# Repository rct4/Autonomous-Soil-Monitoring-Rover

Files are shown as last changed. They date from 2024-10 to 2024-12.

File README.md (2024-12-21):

# Autonomous-Soil-Monitoring-Rover

The autonomous soil monitoring rover is a project that aims to assist commercial farmers and personal gardeners by introducing an automated solution to monitoring soil data.

## Software
Motion plan is currently a naive solution, polling each sensor for feedback. A FreeRTOS solution is currently being developed to schedule sensor data collection and motor output.

## PCB
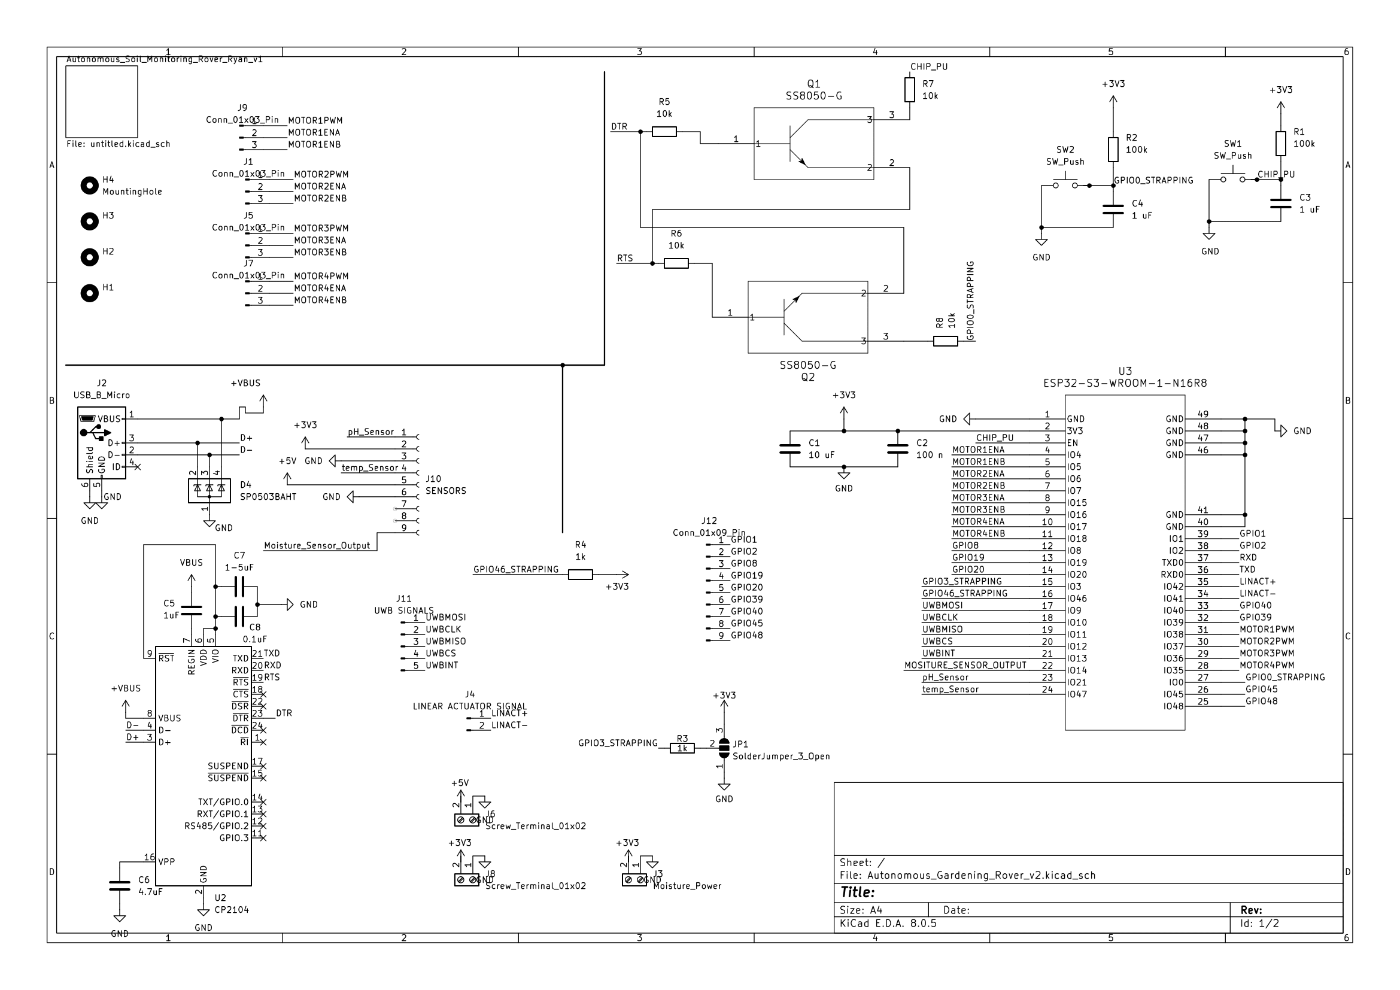
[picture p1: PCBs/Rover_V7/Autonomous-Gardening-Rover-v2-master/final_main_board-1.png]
Rover PCB


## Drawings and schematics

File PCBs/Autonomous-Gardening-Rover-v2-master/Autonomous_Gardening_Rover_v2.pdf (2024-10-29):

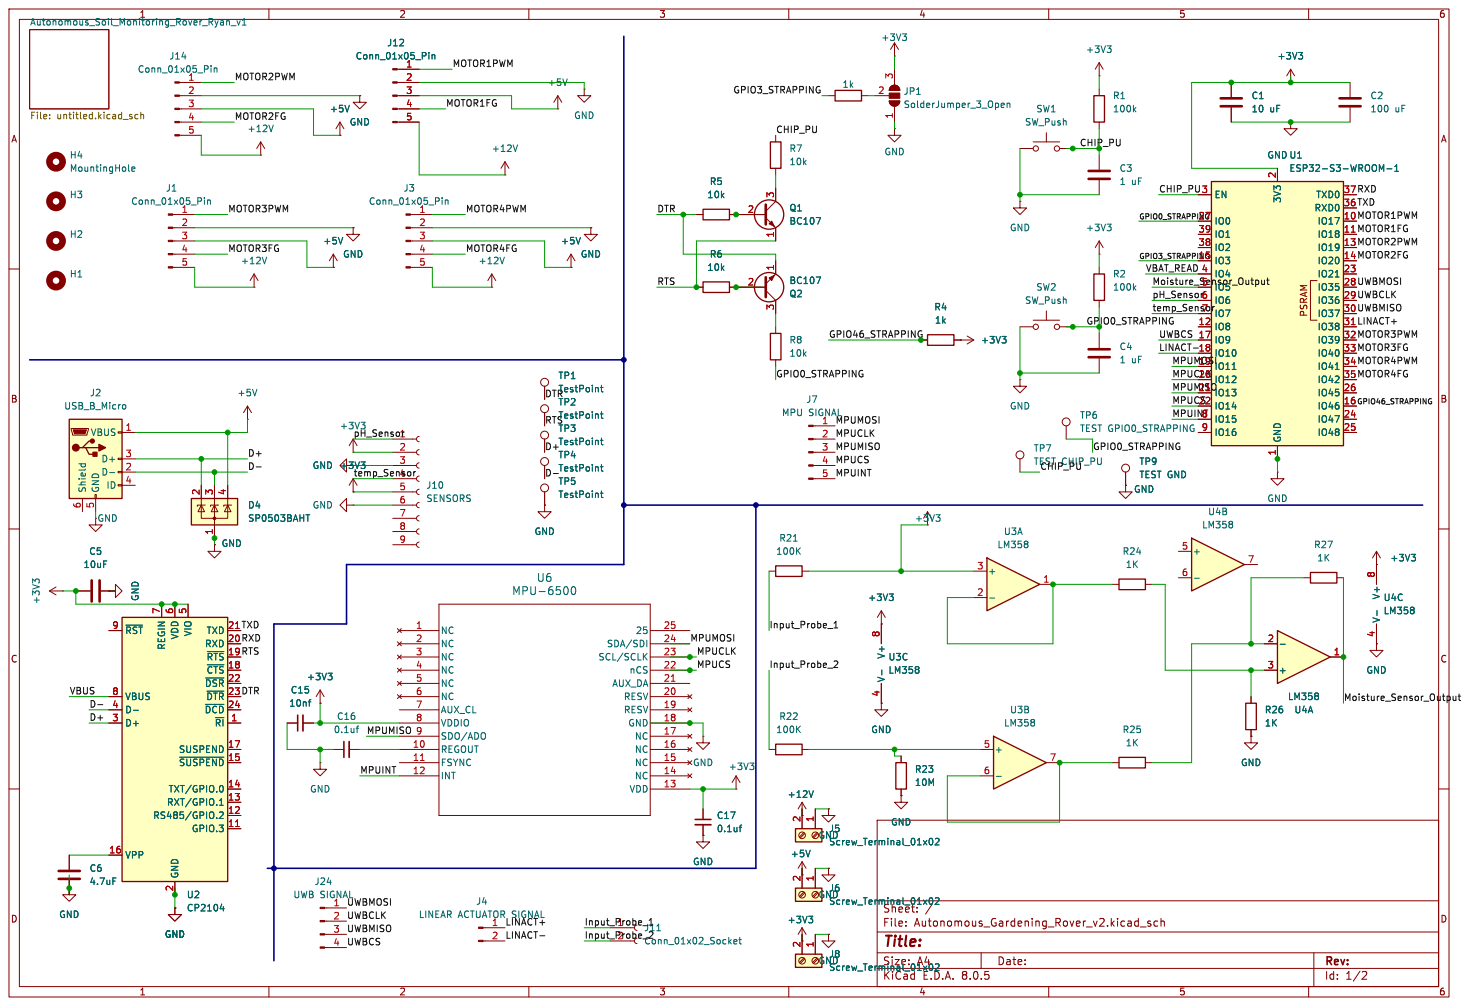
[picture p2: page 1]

LINACT- MPUMOSI MPUCLK MPUMISO MPUINT MPUCS

2 RXD 20 TXD 21 ~{DSR} 22 ~{DTR} 23 ~{DCD} 24 D+ 3 D- 4 VIO

Id: 1/2 Title: File: Autonomous_Gardening_Rover_v2.kicad_sch Sheet: /

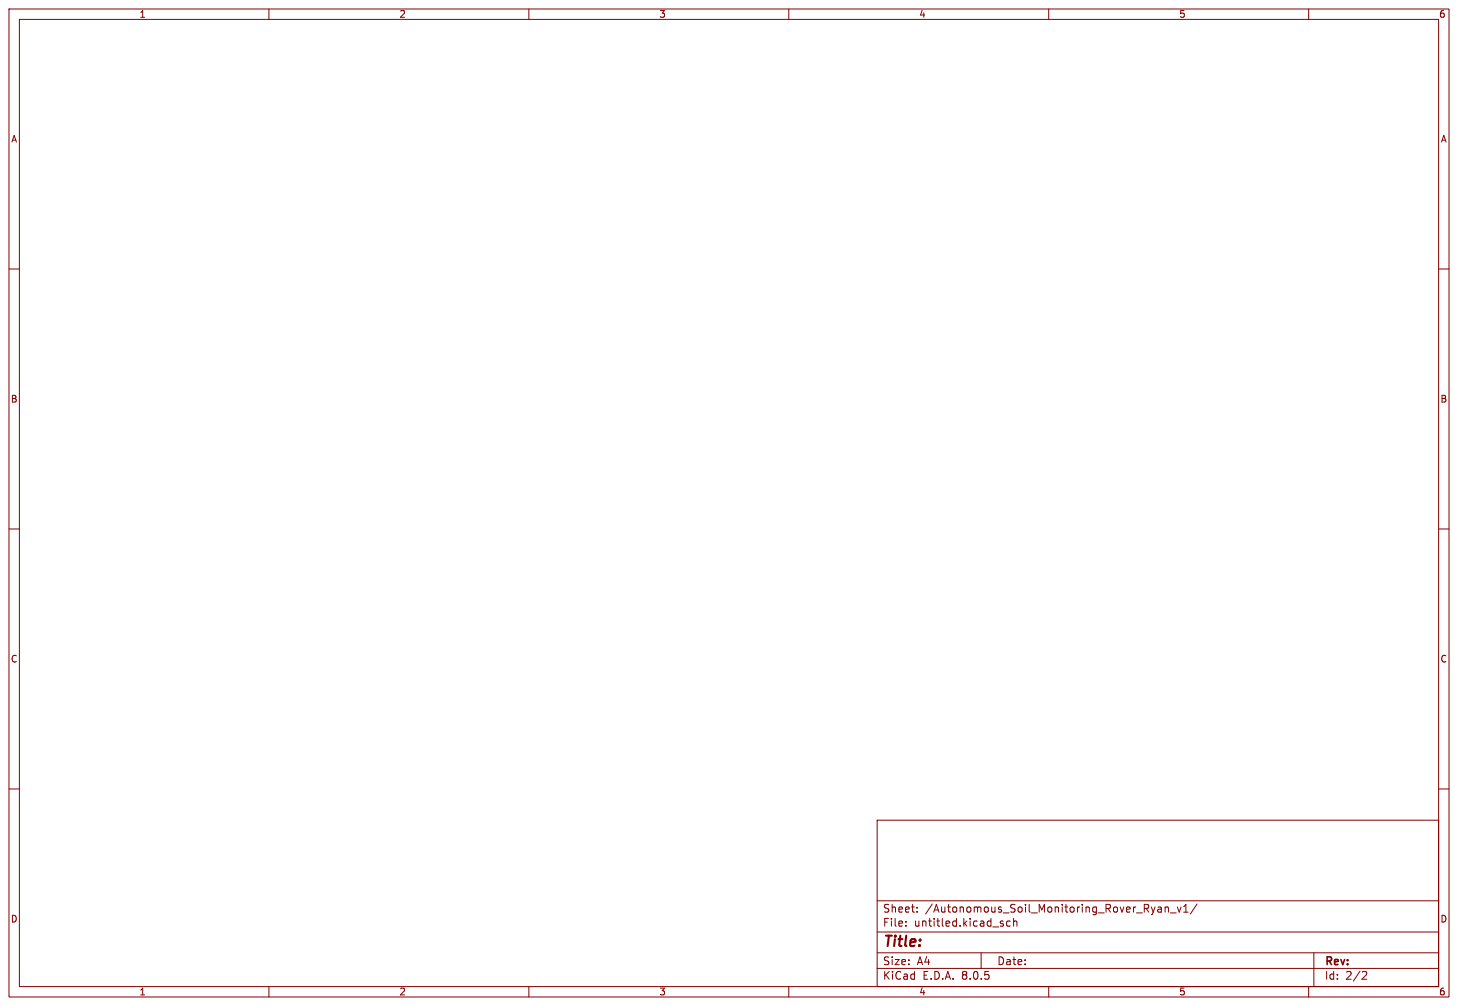
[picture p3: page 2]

Id: 2/2 Title: File: untitled.kicad_sch Sheet: /Autonomous_Soil_Monitoring_Rover_Ryan_v1/

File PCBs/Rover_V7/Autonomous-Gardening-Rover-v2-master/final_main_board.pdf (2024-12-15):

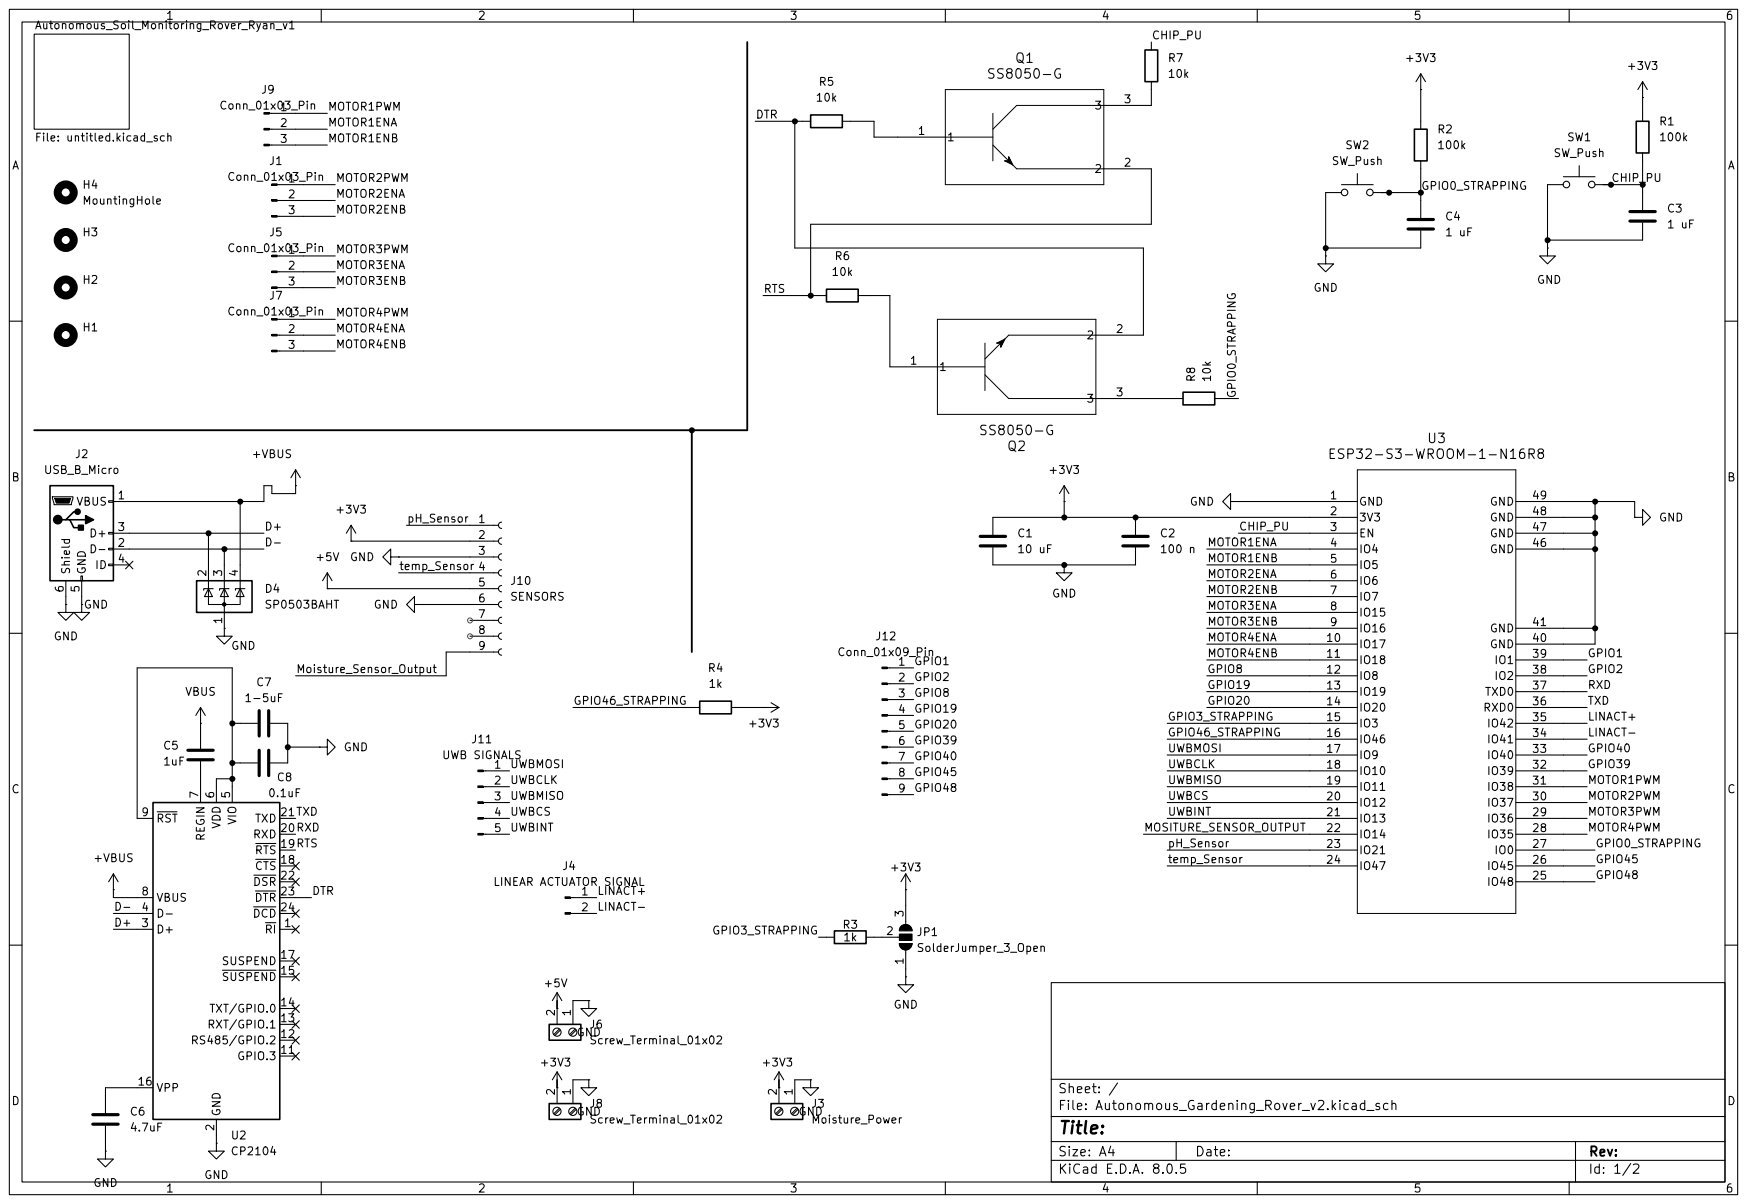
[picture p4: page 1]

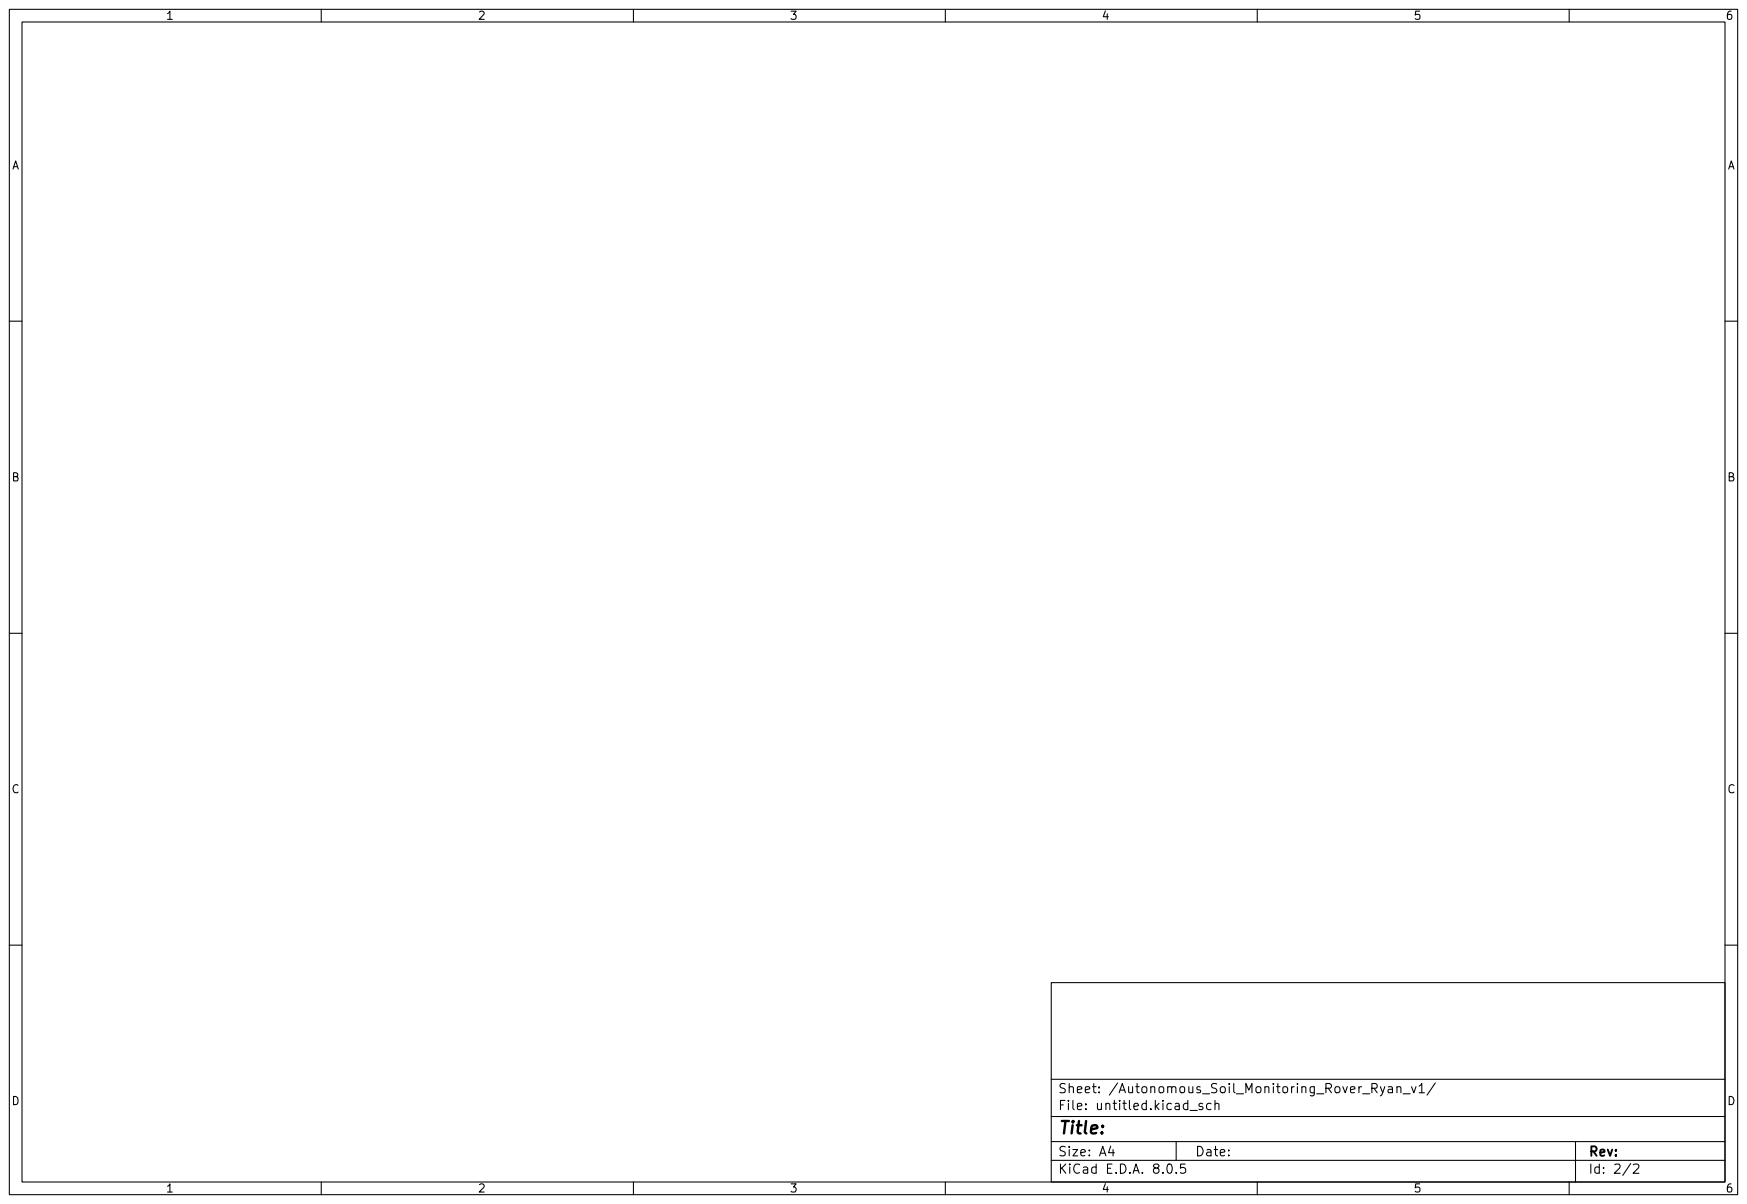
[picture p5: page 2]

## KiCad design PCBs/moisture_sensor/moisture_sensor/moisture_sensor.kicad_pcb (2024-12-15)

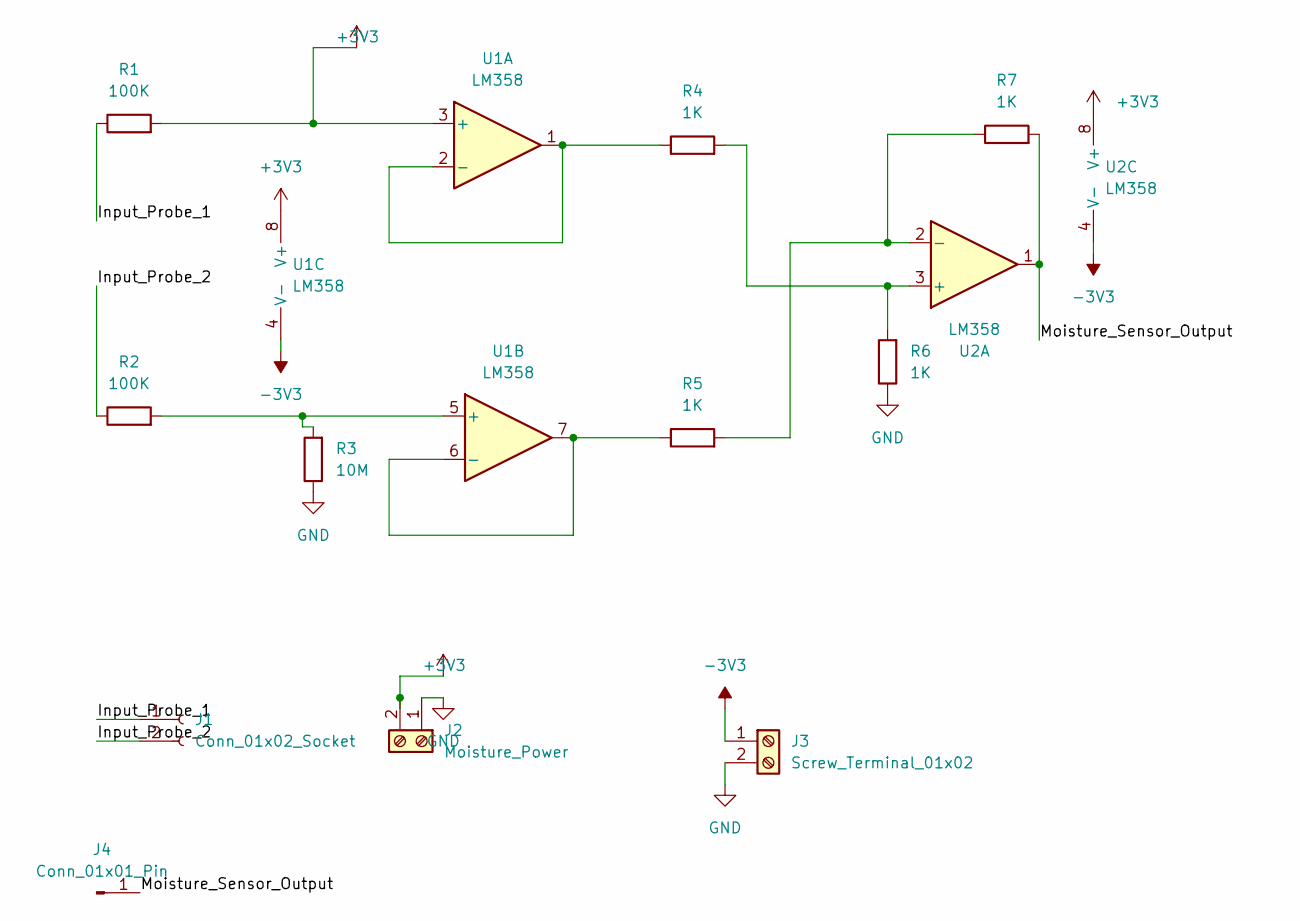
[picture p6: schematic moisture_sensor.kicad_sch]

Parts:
J1: Conn_01x02_Socket; PinHeader_1x02_P2.54mm_Vertical
J2: Moisture_Power; TerminalBlock_Phoenix_MKDS-1,5-2-5.08_1x02_P5.08mm_Horizont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
J3: Screw_Terminal_01x02; TerminalBlock_Phoenix_MKDS-1,5-2-5.08_1x02_P5.08mm_Horizont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
J4: Conn_01x01_Pin; PinHeader_1x01_P2.54mm_Vertical
R1, R2: 100K; R_0805_2012Metric_Pad1.20x1.40mm_HandSolder
R3: 10M; R_0805_2012Metric_Pad1.20x1.40mm_HandSolder
R4, R5, R6, R7: 1K; R_0805_2012Metric_Pad1.20x1.40mm_HandSolder
U1, U2: LM358; N08E

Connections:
+3V3: J2.2, R1.2, U1.3 (+), U1.8 (V+), U2.8 (V+)
-3V3: J3.1, U1.4 (V-), U2.4 (V-)
/Input_Probe_1: J1.1, R1.1
/Input_Probe_2: J1.2, R2.1
/Moisture_Sensor_Output: J4.1, R7.2, U2.1
GND: J2.1, J3.2, R3.1, R6.1
unnamed: R4.1, U1.1, U1.2 (-)
unnamed: R2.2, R3.2, U1.5 (+)
unnamed: R5.1, U1.6 (-), U1.7
unnamed: R4.2, R6.2, U2.3 (+)
unnamed: R5.2, R7.1, U2.2 (-)

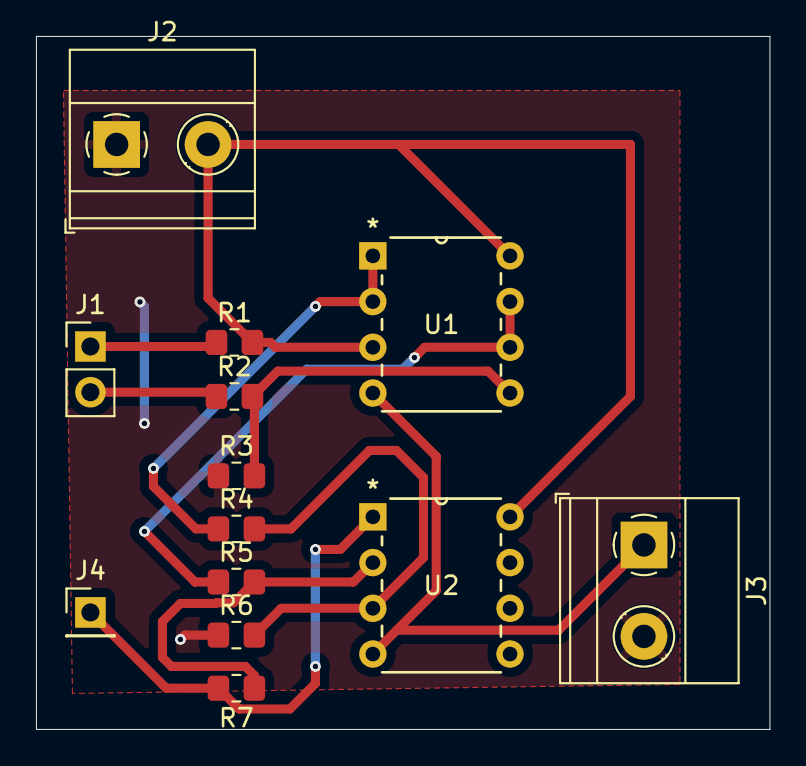
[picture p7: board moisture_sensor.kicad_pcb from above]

Board: 2 copper layers, 40.8 x 38.5 mm, 13 parts (0 on the bottom side), 11 nets.

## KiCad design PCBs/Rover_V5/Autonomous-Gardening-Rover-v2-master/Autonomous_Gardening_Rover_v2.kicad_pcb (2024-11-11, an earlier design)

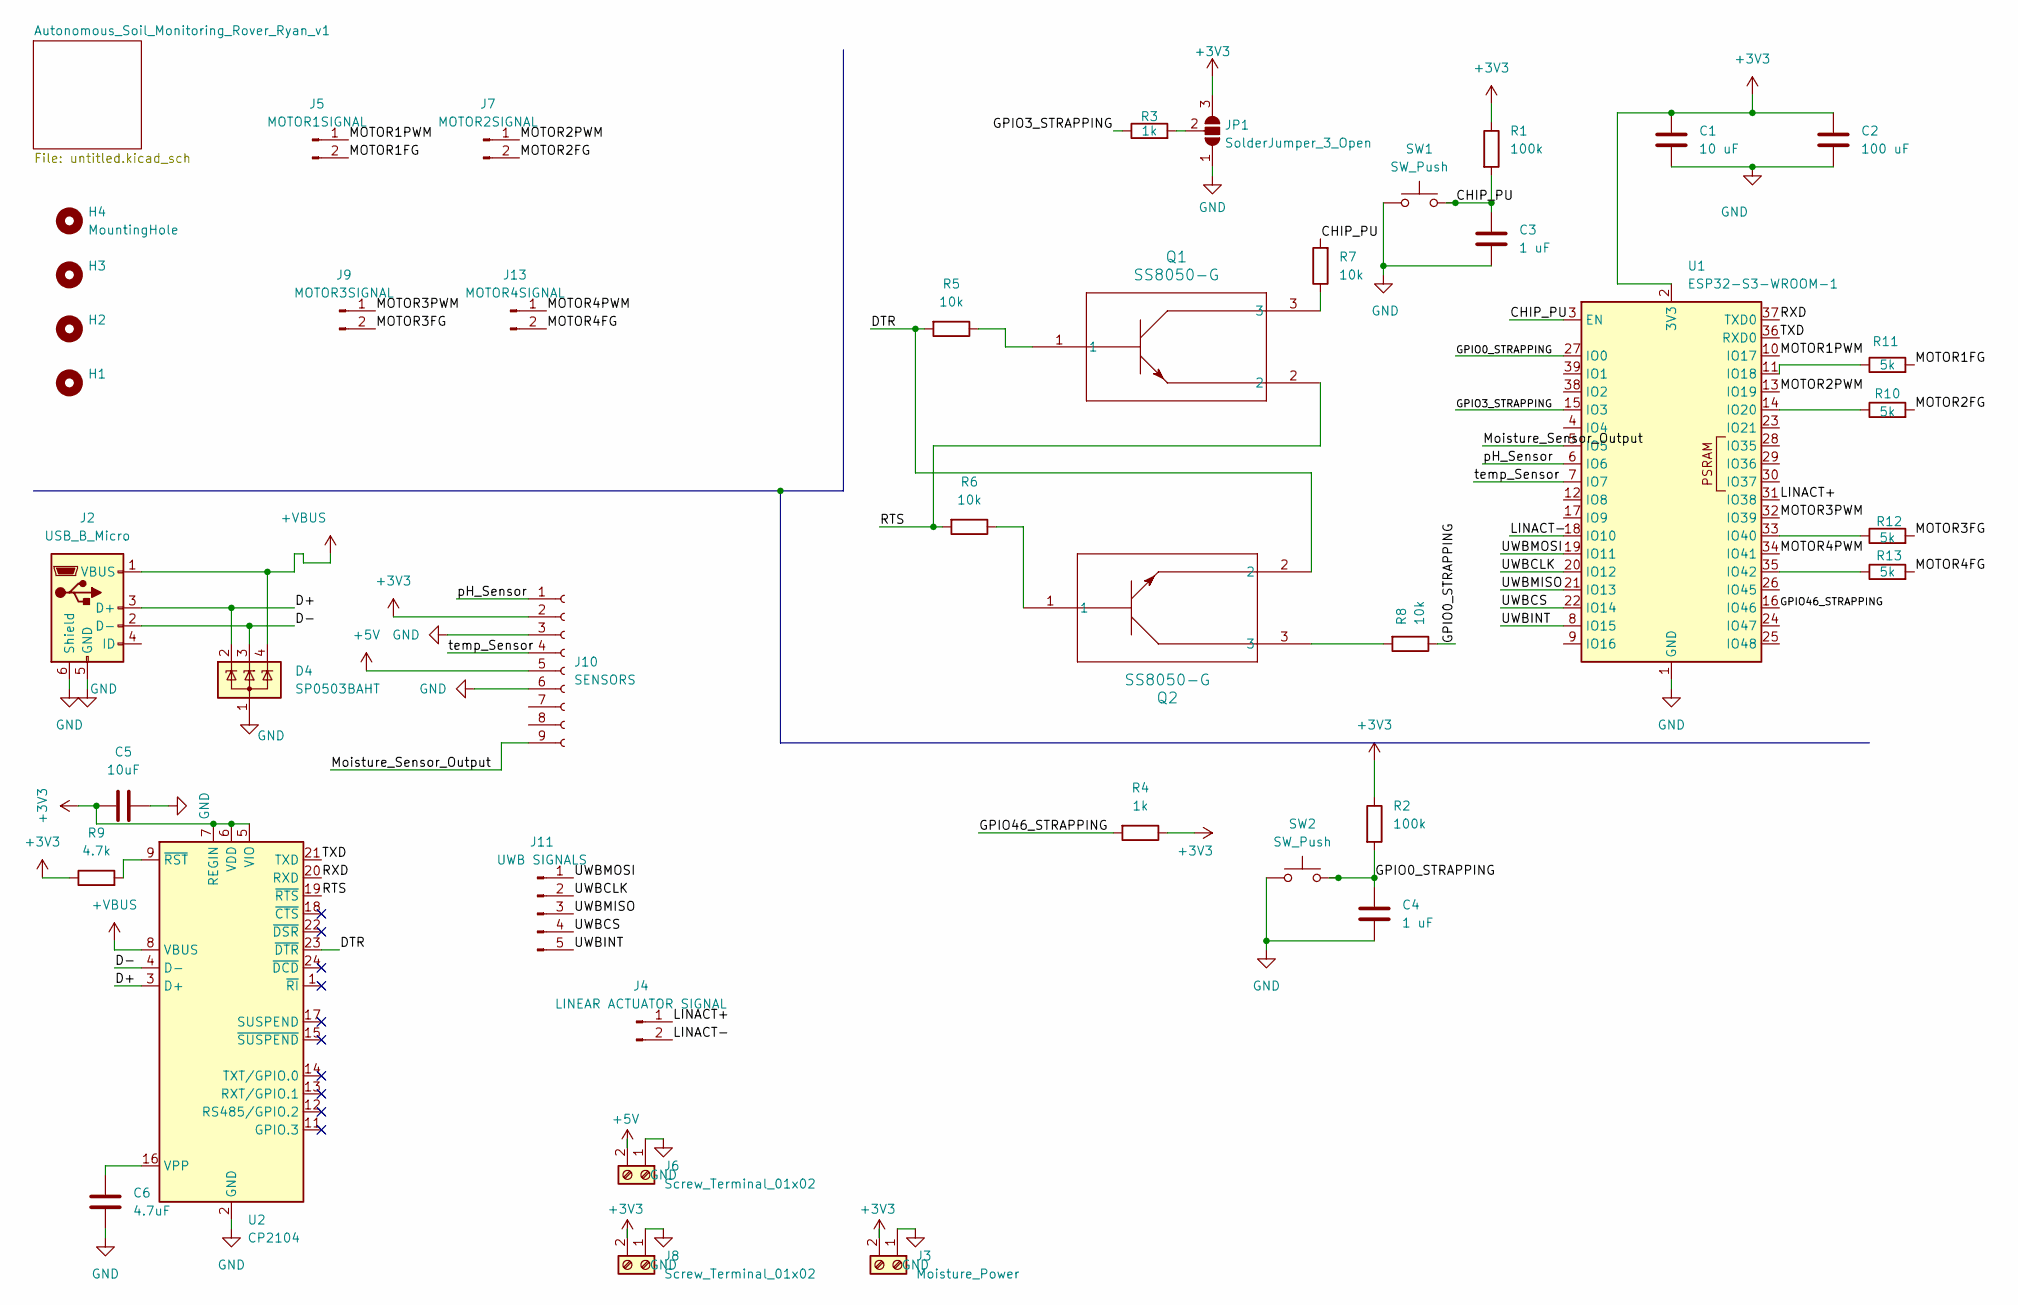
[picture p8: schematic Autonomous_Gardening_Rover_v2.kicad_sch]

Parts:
C1: 10 uF; C_0805_2012Metric_Pad1.18x1.45mm_HandSolder
C2: 100 uF; C_0805_2012Metric_Pad1.18x1.45mm_HandSolder
C3, C4: 1 uF; C_0805_2012Metric_Pad1.18x1.45mm_HandSolder
C5: 10uF; C_0805_2012Metric_Pad1.18x1.45mm_HandSolder
C6: 4.7uF; C_0805_2012Metric_Pad1.18x1.45mm_HandSolder
D4: SP0503BAHT; SOT-143
H1, H2, H3, H4: MountingHole; MountingHole_3.2mm_M3
J2: USB_B_Micro; USB_Micro-B_Molex_47346-0001
J3: Moisture_Power; TerminalBlock_Phoenix_MKDS-1,5-2-5.08_1x02_P5.08mm_Horizont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
J4: LINEAR ACTUATOR SIGNAL; TerminalBlock_Phoenix_MKDS-1,5-2-5.08_1x02_P5.08mm_Horizont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
J5: MOTOR1SIGNAL; TerminalBlock_Phoenix_MKDS-1,5-2-5.08_1x02_P5.08mm_Horizont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
J6, J8: Screw_Terminal_01x02; TerminalBlock_Phoenix_MKDS-1,5-2-5.08_1x02_P5.08mm_Horizont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
J7: MOTOR2SIGNAL; TerminalBlock_Phoenix_MKDS-1,5-2-5.08_1x02_P5.08mm_Horizont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
J9: MOTOR3SIGNAL; TerminalBlock_Phoenix_MKDS-1,5-2-5.08_1x02_P5.08mm_Horizont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
J10: SENSORS; PinHeader_1x09_P2.54mm_Vertical
J11: UWB SIGNALS; PinHeader_1x05_P2.54mm_Vertical
J13: MOTOR4SIGNAL; TerminalBlock_Phoenix_MKDS-1,5-2-5.08_1x02_P5.08mm_Horizont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
JP1: SolderJumper_3_Open; SolderJumper-3_P2.0mm_Open_TrianglePad1.0x1.5mm
Q1, Q2: SS8050-G; TRAN_SS8050-G_CIP
R1, R2: 100k; R_0805_2012Metric_Pad1.20x1.40mm_HandSolder
R3: 1k; R_0805_2012Metric
R4: 1k; R_0805_2012Metric_Pad1.20x1.40mm_HandSolder
R5, R6, R7, R8: 10k; R_0805_2012Metric_Pad1.20x1.40mm_HandSolder
R9: 4.7k; R_0805_2012Metric_Pad1.20x1.40mm_HandSolder
R10, R11, R12, R13: 5k; R_0805_2012Metric_Pad1.20x1.40mm_HandSolder
SW1, SW2: SW_Push; SW_PUSH_6mm_H5mm
U1: ESP32-S3-WROOM-1; ESP32-S3-WROOM-1_EXP
U2: CP2104; QFN-24-1EP_4x4mm_P0.5mm_EP2.6x2.6mm

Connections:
+3V3: C1.1, C2.1, C5.1, J3.2, J8.2, J10.2, JP1.3 (B), R1.1, R2.1, R4.1, R9.1, U1.2 (3V3), U2.5 (VIO), U2.6 (VDD), U2.7 (REGIN)
+5V: J6.2, J10.5
+VBUS: D4.4 (K), J2.1 (VBUS), U2.8 (VBUS)
/CHIP_PU: C3.1, R1.2, R7.2, SW1.2, U1.3 (EN)
/D+: D4.2 (K), J2.3 (D+), U2.3 (D+)
/D-: D4.3 (K), J2.2 (D-), U2.4 (D-)
/DTR: Q2.2, R5.2, U2.23 (~DTR)
/GPIO0_STRAPPING: C4.1, R2.2, R8.1, SW2.2, U1.27 (IO0)
/GPIO3_STRAPPING: R3.1, U1.15 (IO3)
/GPIO46_STRAPPING: R4.2, U1.16 (IO46)
/LINACT+: J4.1, U1.31 (IO38)
/LINACT-: J4.2, U1.18 (IO10)
/MOTOR1FG: J5.2, R11.2
/MOTOR1PWM: J5.1, U1.10 (IO17)
/MOTOR2FG: J7.2, R10.2
/MOTOR2PWM: J7.1, U1.13 (IO19)
/MOTOR3FG: J9.2, R12.2
/MOTOR3PWM: J9.1, U1.32 (IO39)
/MOTOR4FG: J13.2, R13.2
/MOTOR4PWM: J13.1, U1.34 (IO41)
/Moisture_Sensor_Output: J10.9, U1.5 (IO5)
/RTS: Q1.2, R6.2, U2.19 (~RTS)
/RXD: U1.37 (TXD0), U2.20 (RXD)
/TXD: U1.36 (RXD0), U2.21 (TXD)
/UWBCLK: J11.2, U1.20 (IO12)
/UWBCS: J11.4, U1.22 (IO14)
/UWBINT: J11.5, U1.8 (IO15)
/UWBMISO: J11.3, U1.21 (IO13)
/UWBMOSI: J11.1, U1.19 (IO11)
/pH_Sensor: J10.1, U1.6 (IO6)
/temp_Sensor: J10.4, U1.7 (IO7)
GND: C1.2, C2.2, C3.2, C4.2, C5.2, C6.2, D4.1 (A), J2.5 (GND), J2.6 (Shield), J3.1, J6.1, J8.1, J10.3, J10.6, JP1.1 (A), SW1.1, SW2.1, U1.1 (GND), U1.40 (GND), U1.41 (GND), U2.2 (GND), U2.25 (GND)
unnamed: JP1.2 (C), R3.2
unnamed: Q1.1, R5.1
unnamed: Q1.3, R7.1
unnamed: Q2.1, R6.1
unnamed: Q2.3, R8.2
unnamed: R11.1, U1.11 (IO18)
unnamed: R10.1, U1.14 (IO20)
unnamed: R12.1, U1.33 (IO40)
unnamed: R13.1, U1.35 (IO42)
unnamed: C6.1, U2.16 (VPP)
unnamed: R9.2, U2.9 (~RST)

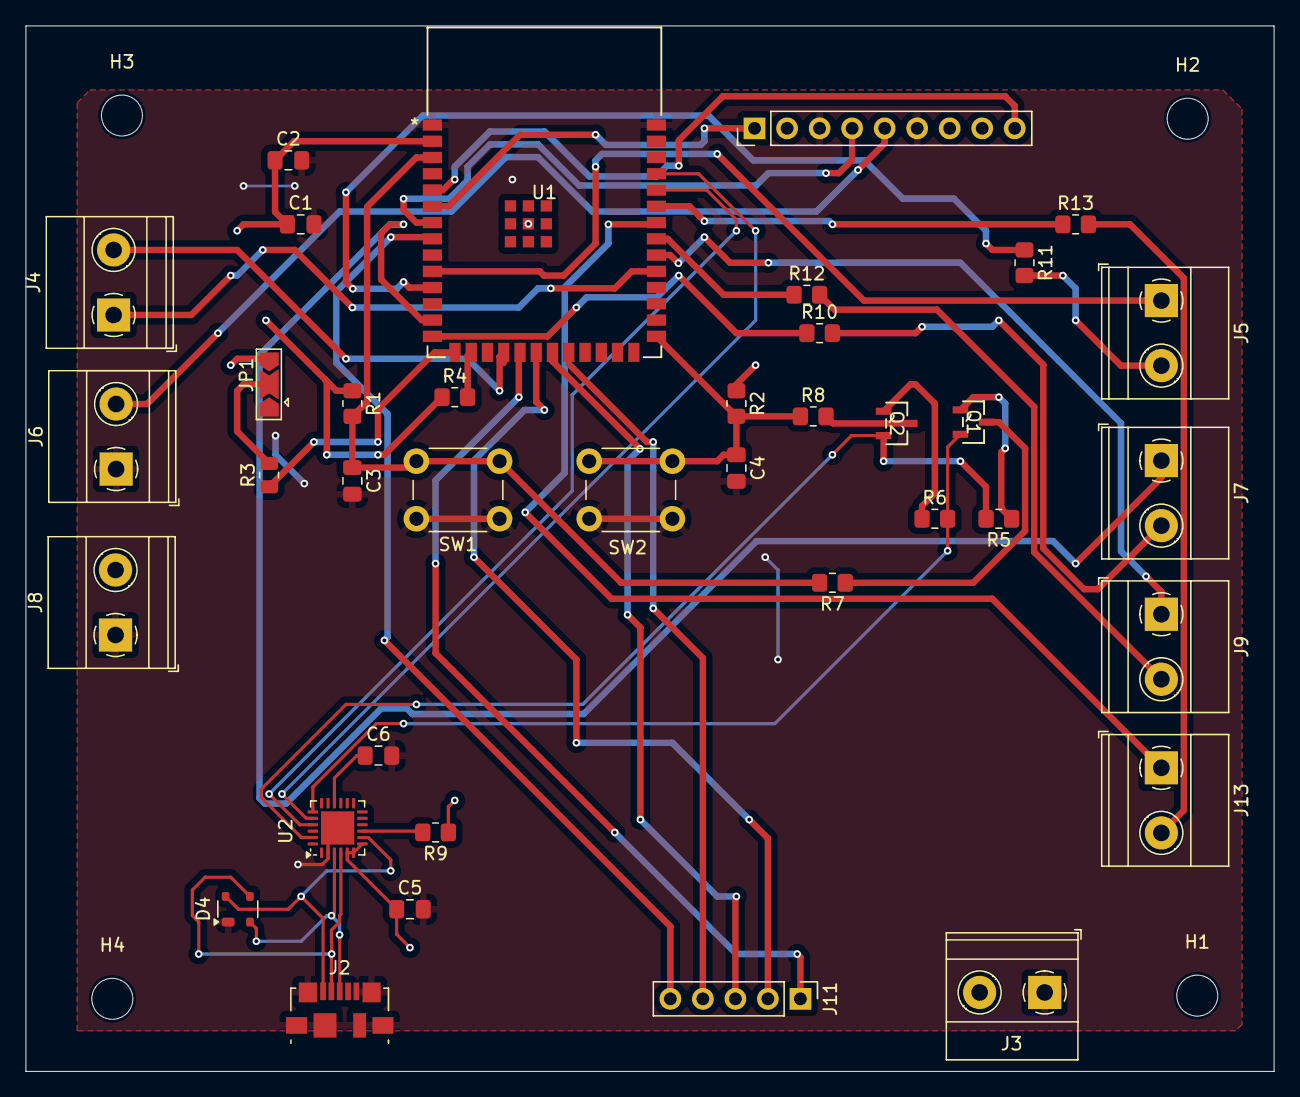
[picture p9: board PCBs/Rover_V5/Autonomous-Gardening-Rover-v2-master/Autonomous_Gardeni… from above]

Board: 2 copper layers, 97.5 x 81.7 mm, 42 parts (0 on the bottom side), 43 nets.

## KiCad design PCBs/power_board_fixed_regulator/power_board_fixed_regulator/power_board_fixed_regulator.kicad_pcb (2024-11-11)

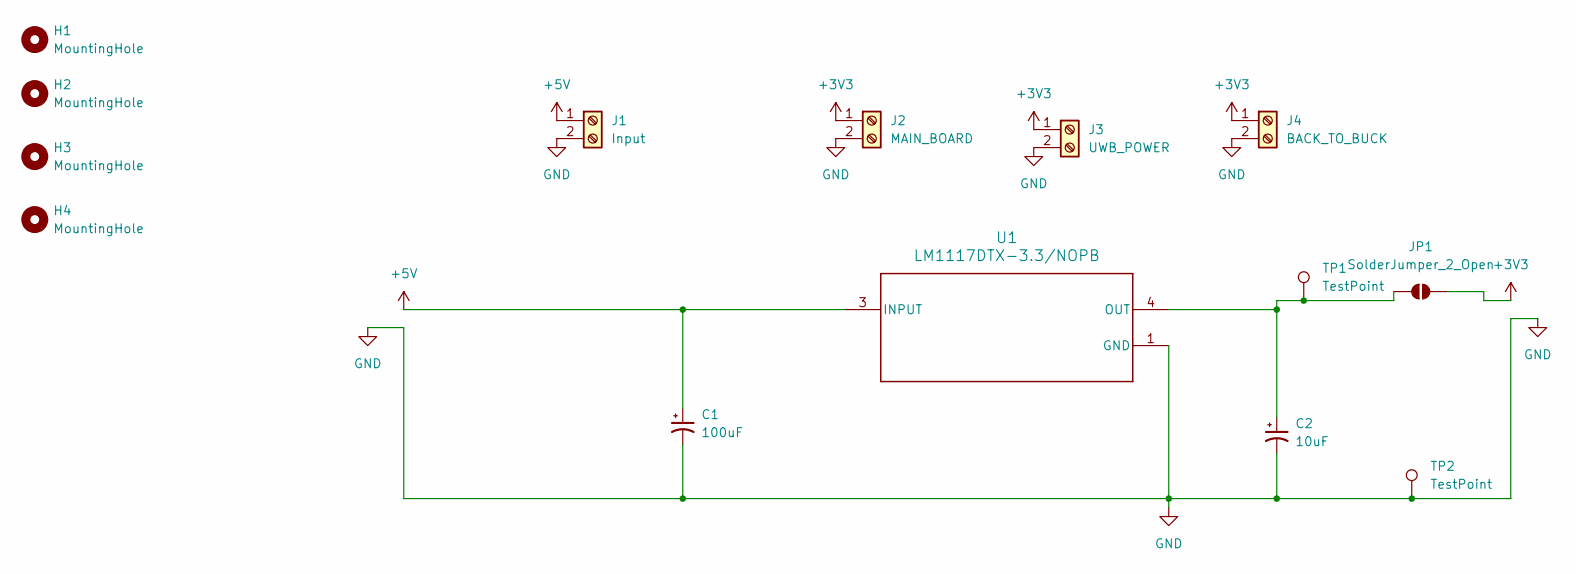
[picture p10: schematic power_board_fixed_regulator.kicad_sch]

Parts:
C1: 100uF; C_0805_2012Metric_Pad1.18x1.45mm_HandSolder
C2: 10uF; C_0805_2012Metric_Pad1.18x1.45mm_HandSolder
H1, H2, H3, H4: MountingHole; MountingHole_3.2mm_M3
J1: Input; TerminalBlock_Phoenix_MKDS-1,5-2-5.08_1x02_P5.08mm_Horizont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
J2: MAIN_BOARD; TerminalBlock_Phoenix_MKDS-1,5-2-5.08_1x02_P5.08mm_Horizont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
J3: UWB_POWER; TerminalBlock_Phoenix_MKDS-1,5-2-5.08_1x02_P5.08mm_Horizont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
J4: BACK_TO_BUCK; TerminalBlock_Phoenix_MKDS-1,5-2-5.08_1x02_P5.08mm_Horizont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
JP1: SolderJumper_2_Open; SolderJumper-2_P1.3mm_Open_RoundedPad1.0x1.5mm
TP1, TP2: TestPoint; TestPoint_Pad_2.5x2.5mm
U1: LM1117DTX-3.3/NOPB; NDP0003B

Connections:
+3V3: J2.1, J3.1, J4.1, JP1.2 (B)
+5V: C1.1, J1.1, U1.3 (INPUT)
GND: C1.2, C2.2, J1.2, J2.2, J3.2, J4.2, TP2.1, U1.1 (GND)
unnamed: C2.1, JP1.1 (A), TP1.1, U1.4 (OUT)

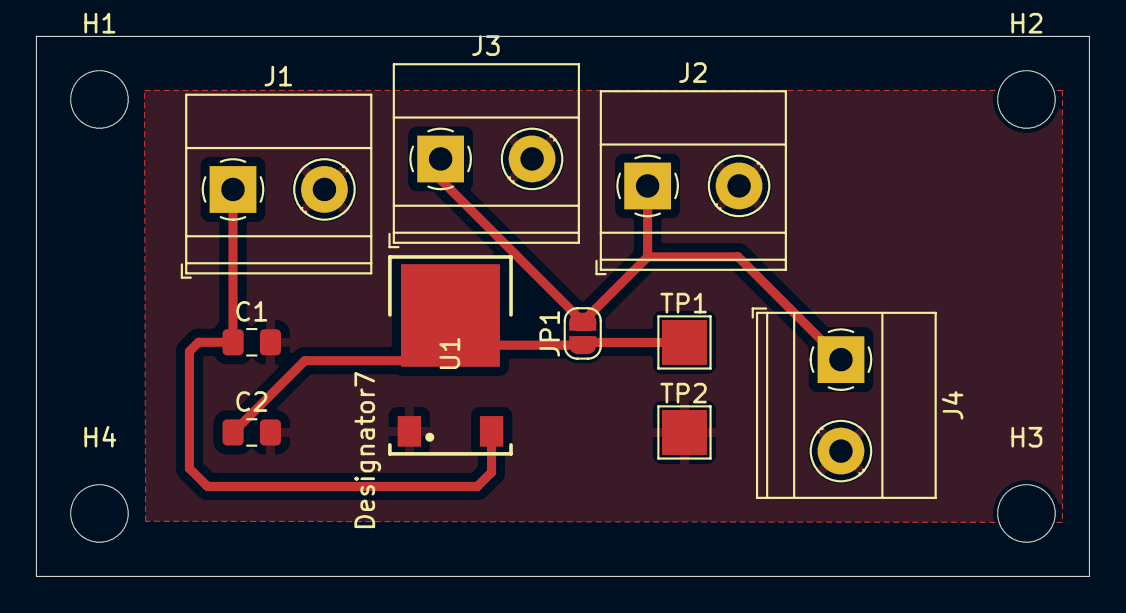
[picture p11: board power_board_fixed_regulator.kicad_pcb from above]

Board: 2 copper layers, 58.5 x 30.0 mm, 14 parts (0 on the bottom side), 4 nets.

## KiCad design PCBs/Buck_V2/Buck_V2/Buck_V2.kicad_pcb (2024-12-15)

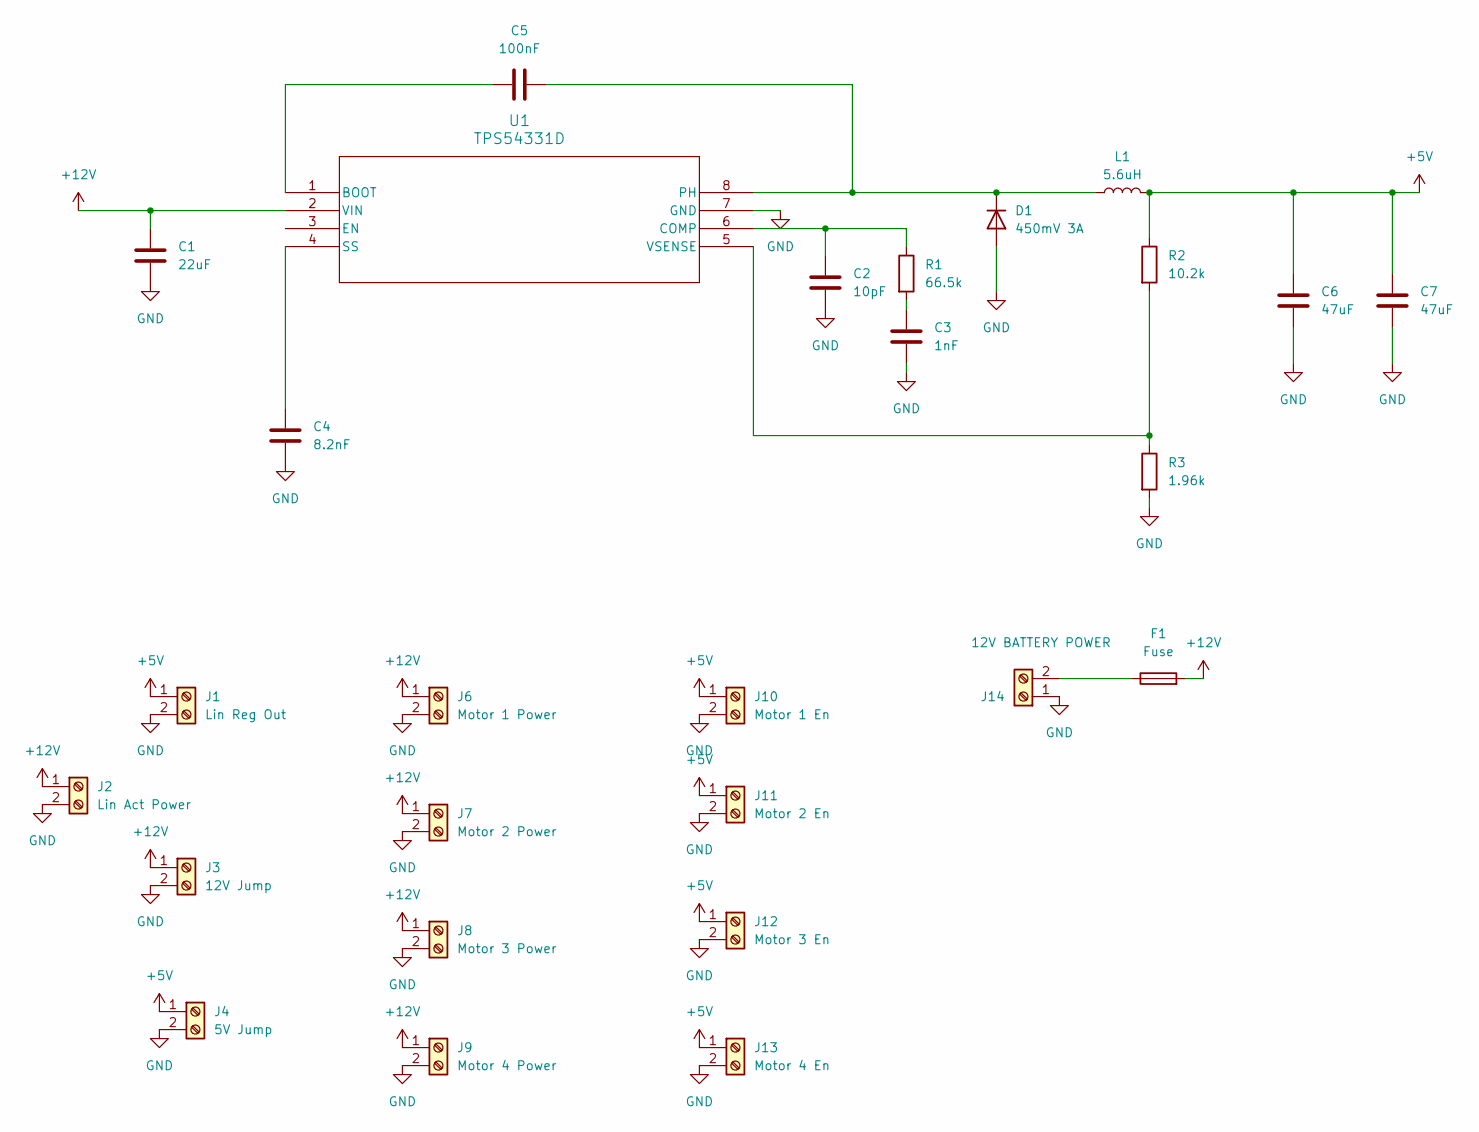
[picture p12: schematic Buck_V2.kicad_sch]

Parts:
C1: 22uF; C_0805_2012Metric_Pad1.18x1.45mm_HandSolder
C2: 10pF; C_0805_2012Metric_Pad1.18x1.45mm_HandSolder
C3: 1nF; C_0805_2012Metric_Pad1.18x1.45mm_HandSolder
C4: 8.2nF; C_1206_3216Metric_Pad1.33x1.80mm_HandSolder
C5: 100nF; C_0805_2012Metric_Pad1.18x1.45mm_HandSolder
C6, C7: 47uF; C_0805_2012Metric_Pad1.18x1.45mm_HandSolder
D1: 450mV 3A; DIODE_SODB340_2P92X4P6_DIO
F1: Fuse; Fuseholder_Littelfuse_Nano2_154x
J1: Lin Reg Out; TerminalBlock_Phoenix_MKDS-1,5-2-5.08_1x02_P5.08mm_Horizont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
J2: Lin Act Power; TerminalBlock_Phoenix_MKDS-1,5-2-5.08_1x02_P5.08mm_Horizont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
J3: 12V Jump; TerminalBlock_Phoenix_MKDS-1,5-2-5.08_1x02_P5.08mm_Horizont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
J4: 5V Jump; TerminalBlock_Phoenix_MKDS-1,5-2-5.08_1x02_P5.08mm_Horizont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
J6: Motor 1 Power; TerminalBlock_Phoenix_MKDS-1,5-2-5.08_1x02_P5.08mm_Horizont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
J7: Motor 2 Power; TerminalBlock_Phoenix_MKDS-1,5-2-5.08_1x02_P5.08mm_Horizont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
J8: Motor 3 Power; TerminalBlock_Phoenix_MKDS-1,5-2-5.08_1x02_P5.08mm_Horizont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
J9: Motor 4 Power; TerminalBlock_Phoenix_MKDS-1,5-2-5.08_1x02_P5.08mm_Horizont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
J10: Motor 1 En; TerminalBlock_Phoenix_MKDS-1,5-2-5.08_1x02_P5.08mm_Horizont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
J11: Motor 2 En; TerminalBlock_Phoenix_MKDS-1,5-2-5.08_1x02_P5.08mm_Horizont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
J12: Motor 3 En; TerminalBlock_Phoenix_MKDS-1,5-2-5.08_1x02_P5.08mm_Horizont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
J13: Motor 4 En; TerminalBlock_Phoenix_MKDS-1,5-2-5.08_1x02_P5.08mm_Horizont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
J14: 12V BATTERY POWER; TerminalBlock_Phoenix_MKDS-1,5-2-5.08_1x02_P5.08mm_Horizont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
L1: 5.6uH; IND25X25CZ
R1: 66.5k; R_0805_2012Metric_Pad1.20x1.40mm_HandSolder
R2: 10.2k; R_0805_2012Metric_Pad1.20x1.40mm_HandSolder
R3: 1.96k; R_0805_2012Metric_Pad1.20x1.40mm_HandSolder
U1: TPS54331D; D8

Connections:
+5V: C6.1, C7.1, J1.1, J4.1, J10.1, J11.1, J12.1, J13.1, L1.2, R2.1
+12V: C1.1, F1.2, J2.1, J3.1, J6.1, J7.1, J8.1, J9.1, U1.2 (VIN)
GND: C1.2, C2.2, C3.2, C4.2, C6.2, C7.2, D1.2 (A), J1.2, J2.2, J3.2, J4.2, J6.2, J7.2, J8.2, J9.2, J10.2, J11.2, J12.2, J13.2, J14.1, R3.2, U1.7 (GND)
unnamed: C3.1, R1.2
unnamed: C5.2, D1.1 (K), L1.1, U1.8 (PH)
unnamed: F1.1, J14.2
unnamed: C5.1, U1.1 (BOOT)
unnamed: C2.1, R1.1, U1.6 (COMP)
unnamed: C4.1, U1.4 (SS)
unnamed: R2.2, R3.1, U1.5 (VSENSE)

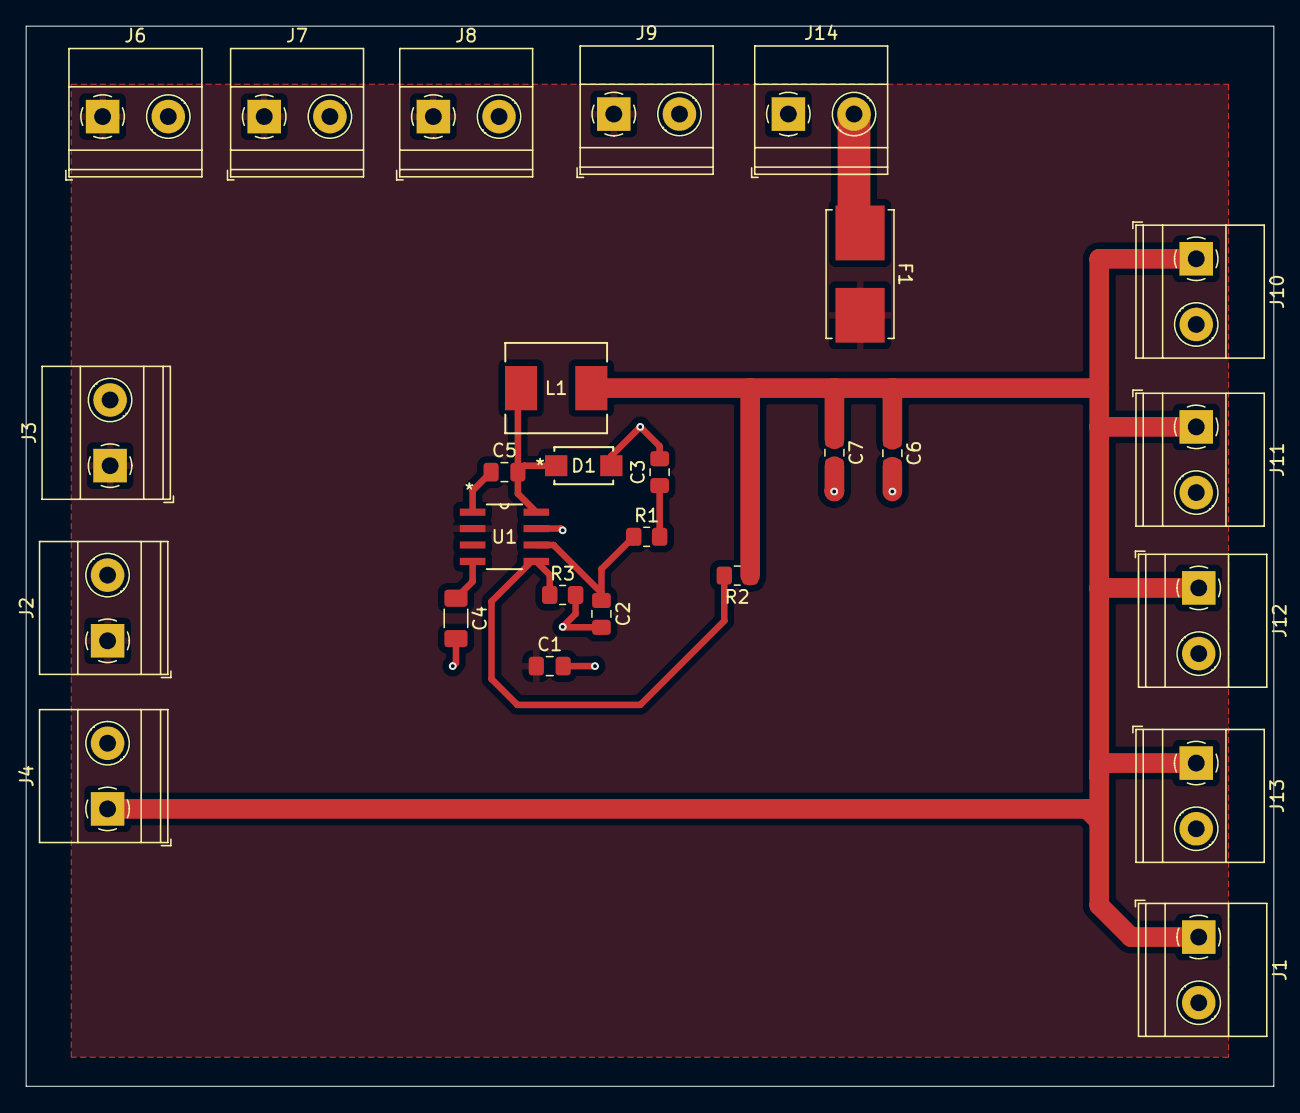
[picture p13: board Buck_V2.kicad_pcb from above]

Board: 2 copper layers, 96.5 x 82.0 mm, 27 parts (0 on the bottom side), 10 nets.

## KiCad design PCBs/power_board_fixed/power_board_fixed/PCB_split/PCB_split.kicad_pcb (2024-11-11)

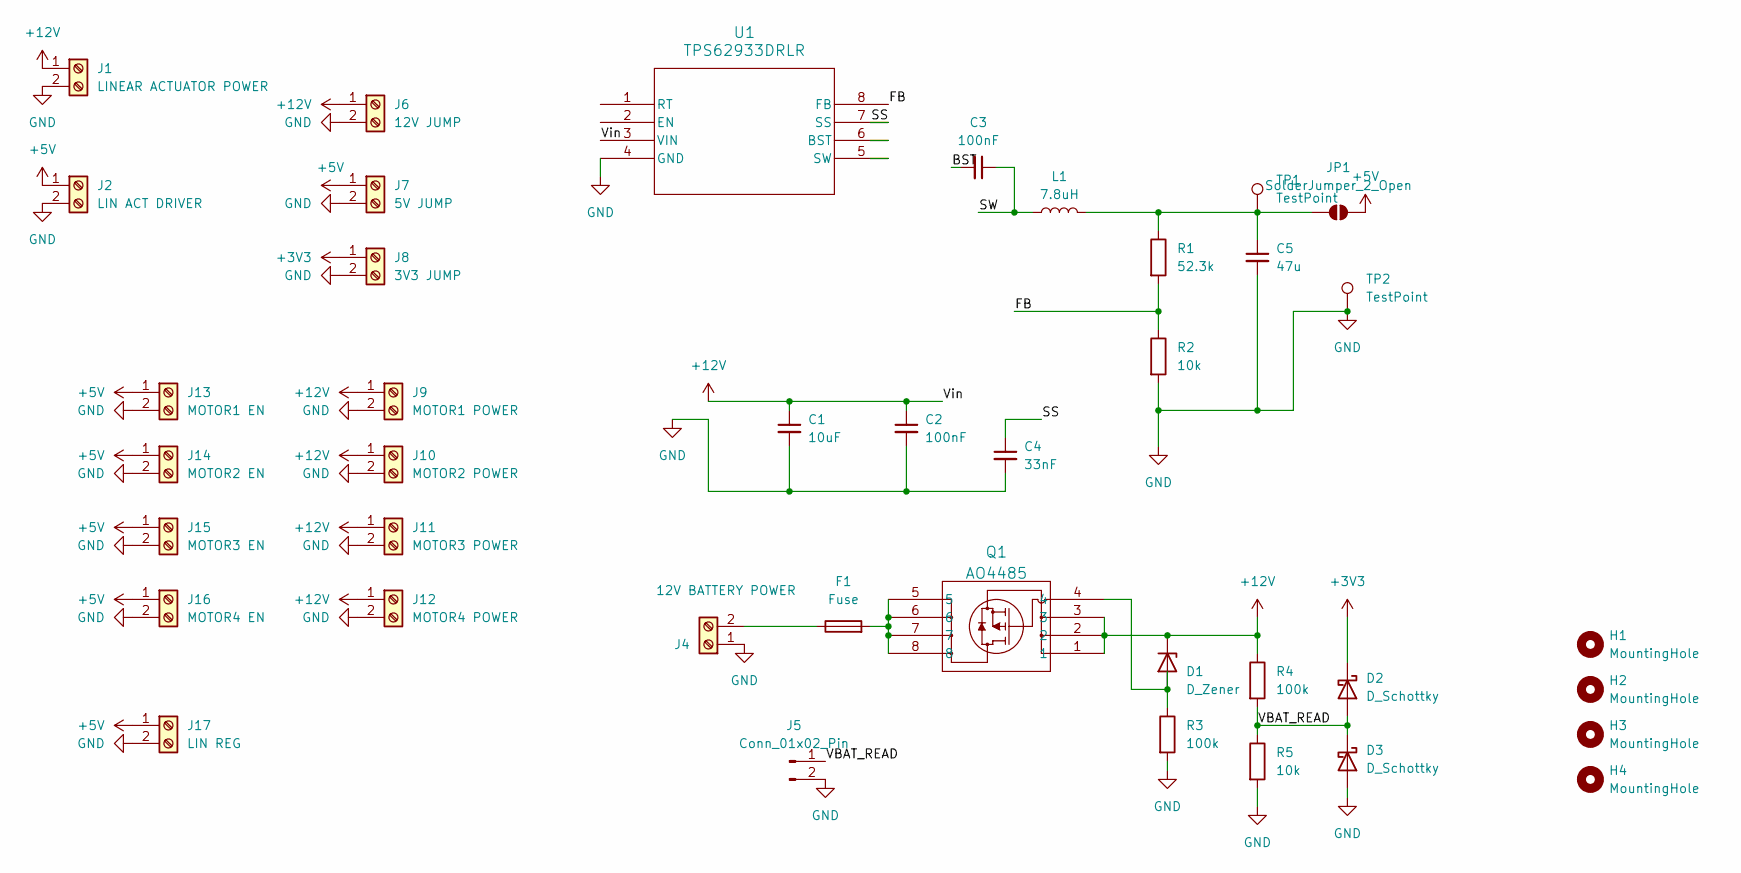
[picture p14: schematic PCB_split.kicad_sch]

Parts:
C1: 10uF; C_0805_2012Metric_Pad1.18x1.45mm_HandSolder
C2, C3: 100nF; C_0805_2012Metric_Pad1.18x1.45mm_HandSolder
C4: 33nF; C_0805_2012Metric_Pad1.18x1.45mm_HandSolder
C5: 47u; C_0805_2012Metric_Pad1.18x1.45mm_HandSolder
D1: D_Zener; D_SOD-123
D2, D3: D_Schottky; TSOT-23_HandSoldering
F1: Fuse; Fuseholder_Littelfuse_Nano2_154x
H1, H2, H3, H4: MountingHole; MountingHole_3.2mm_M3
J1: LINEAR ACTUATOR POWER; TerminalBlock_Phoenix_MKDS-1,5-2-5.08_1x02_P5.08mm_Horizont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
J2: LIN ACT DRIVER; TerminalBlock_Phoenix_MKDS-1,5-2-5.08_1x02_P5.08mm_Horizont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
J4: 12V BATTERY POWER; TerminalBlock_Phoenix_MKDS-1,5-2-5.08_1x02_P5.08mm_Horizont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
J5: Conn_01x02_Pin; TerminalBlock_Phoenix_MKDS-1,5-2-5.08_1x02_P5.08mm_Horizont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
J6: 12V JUMP; TerminalBlock_Phoenix_MKDS-1,5-2-5.08_1x02_P5.08mm_Horizont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
J7: 5V JUMP; TerminalBlock_Phoenix_MKDS-1,5-2-5.08_1x02_P5.08mm_Horizont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
J8: 3V3 JUMP; TerminalBlock_Phoenix_MKDS-1,5-2-5.08_1x02_P5.08mm_Horizont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
J9: MOTOR1 POWER; TerminalBlock_Phoenix_MKDS-1,5-2-5.08_1x02_P5.08mm_Horizont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
J10: MOTOR2 POWER; TerminalBlock_Phoenix_MKDS-1,5-2-5.08_1x02_P5.08mm_Horizont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
J11: MOTOR3 POWER; TerminalBlock_Phoenix_MKDS-1,5-2-5.08_1x02_P5.08mm_Horizont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
J12: MOTOR4 POWER; TerminalBlock_Phoenix_MKDS-1,5-2-5.08_1x02_P5.08mm_Horizont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
J13: MOTOR1 EN; TerminalBlock_Phoenix_MKDS-1,5-2-5.08_1x02_P5.08mm_Horizont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
J14: MOTOR2 EN; TerminalBlock_Phoenix_MKDS-1,5-2-5.08_1x02_P5.08mm_Horizont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
J15: MOTOR3 EN; TerminalBlock_Phoenix_MKDS-1,5-2-5.08_1x02_P5.08mm_Horizont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
J16: MOTOR4 EN; TerminalBlock_Phoenix_MKDS-1,5-2-5.08_1x02_P5.08mm_Horizont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
J17: LIN REG; TerminalBlock_Phoenix_MKDS-1,5-2-5.08_1x02_P5.08mm_Horizont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
JP1: SolderJumper_2_Open; SolderJumper-2_P1.3mm_Open_RoundedPad1.0x1.5mm
L1: 7.8uH; L_0201_0603Metric_Pad0.64x0.40mm_HandSolder
Q1: AO4485; SO8SOP-8L_AOS
R1: 52.3k; R_0805_2012Metric_Pad1.20x1.40mm_HandSolder
R2, R5: 10k; R_0805_2012Metric_Pad1.20x1.40mm_HandSolder
R3, R4: 100k; R_0805_2012Metric_Pad1.20x1.40mm_HandSolder
TP1, TP2: TestPoint; TestPoint_Pad_2.5x2.5mm
U1: TPS62933DRLR; SOT5X3-8_DRL_TEX

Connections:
+3V3: D2.1 (K), J8.1
+5V: J2.1, J7.1, J13.1, J14.1, J15.1, J16.1, J17.1, JP1.2 (B)
+12V: C1.1, C2.1, D1.1 (K), J1.1, J6.1, J9.1, J10.1, J11.1, J12.1, Q1.1, Q1.2, Q1.3, R4.1, U1.3 (VIN)
/BST: C3.2
/FB: R1.2, R2.1, U1.8 (FB)
/SS: C4.1, U1.7 (SS)
/SW: C3.1, L1.1
/VBAT_READ: D2.2 (A), D3.1 (K), J5.1, R4.2, R5.1
GND: C1.2, C2.2, C4.2, C5.2, D3.2 (A), J1.2, J2.2, J4.1, J5.2, J6.2, J7.2, J8.2, J9.2, J10.2, J11.2, J12.2, J13.2, J14.2, J15.2, J16.2, J17.2, R2.2, R3.2, R5.2, TP2.1, U1.4 (GND)
unnamed: D1.2 (A), Q1.4, R3.1
unnamed: F1.2, Q1.5, Q1.6, Q1.7, Q1.8
unnamed: F1.1, J4.2
unnamed: C5.1, JP1.1 (A), L1.2, R1.1, TP1.1

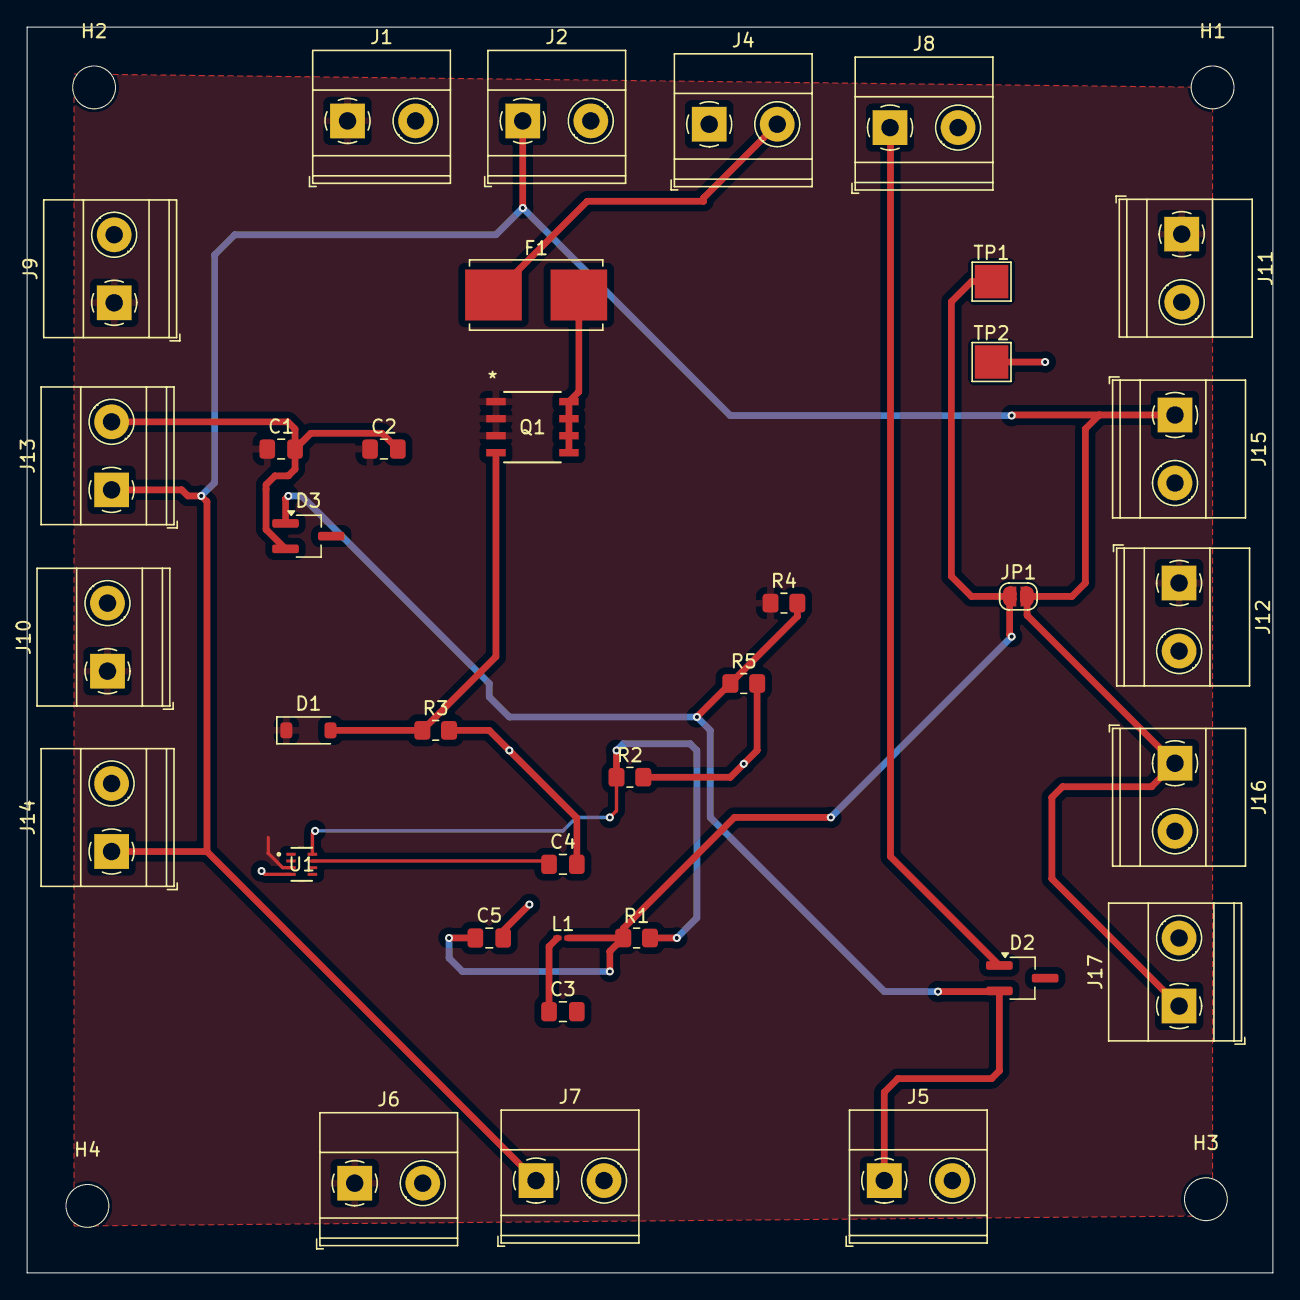
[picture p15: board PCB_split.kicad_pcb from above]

Board: 2 copper layers, 93.0 x 93.0 mm, 40 parts (0 on the bottom side), 12 nets.

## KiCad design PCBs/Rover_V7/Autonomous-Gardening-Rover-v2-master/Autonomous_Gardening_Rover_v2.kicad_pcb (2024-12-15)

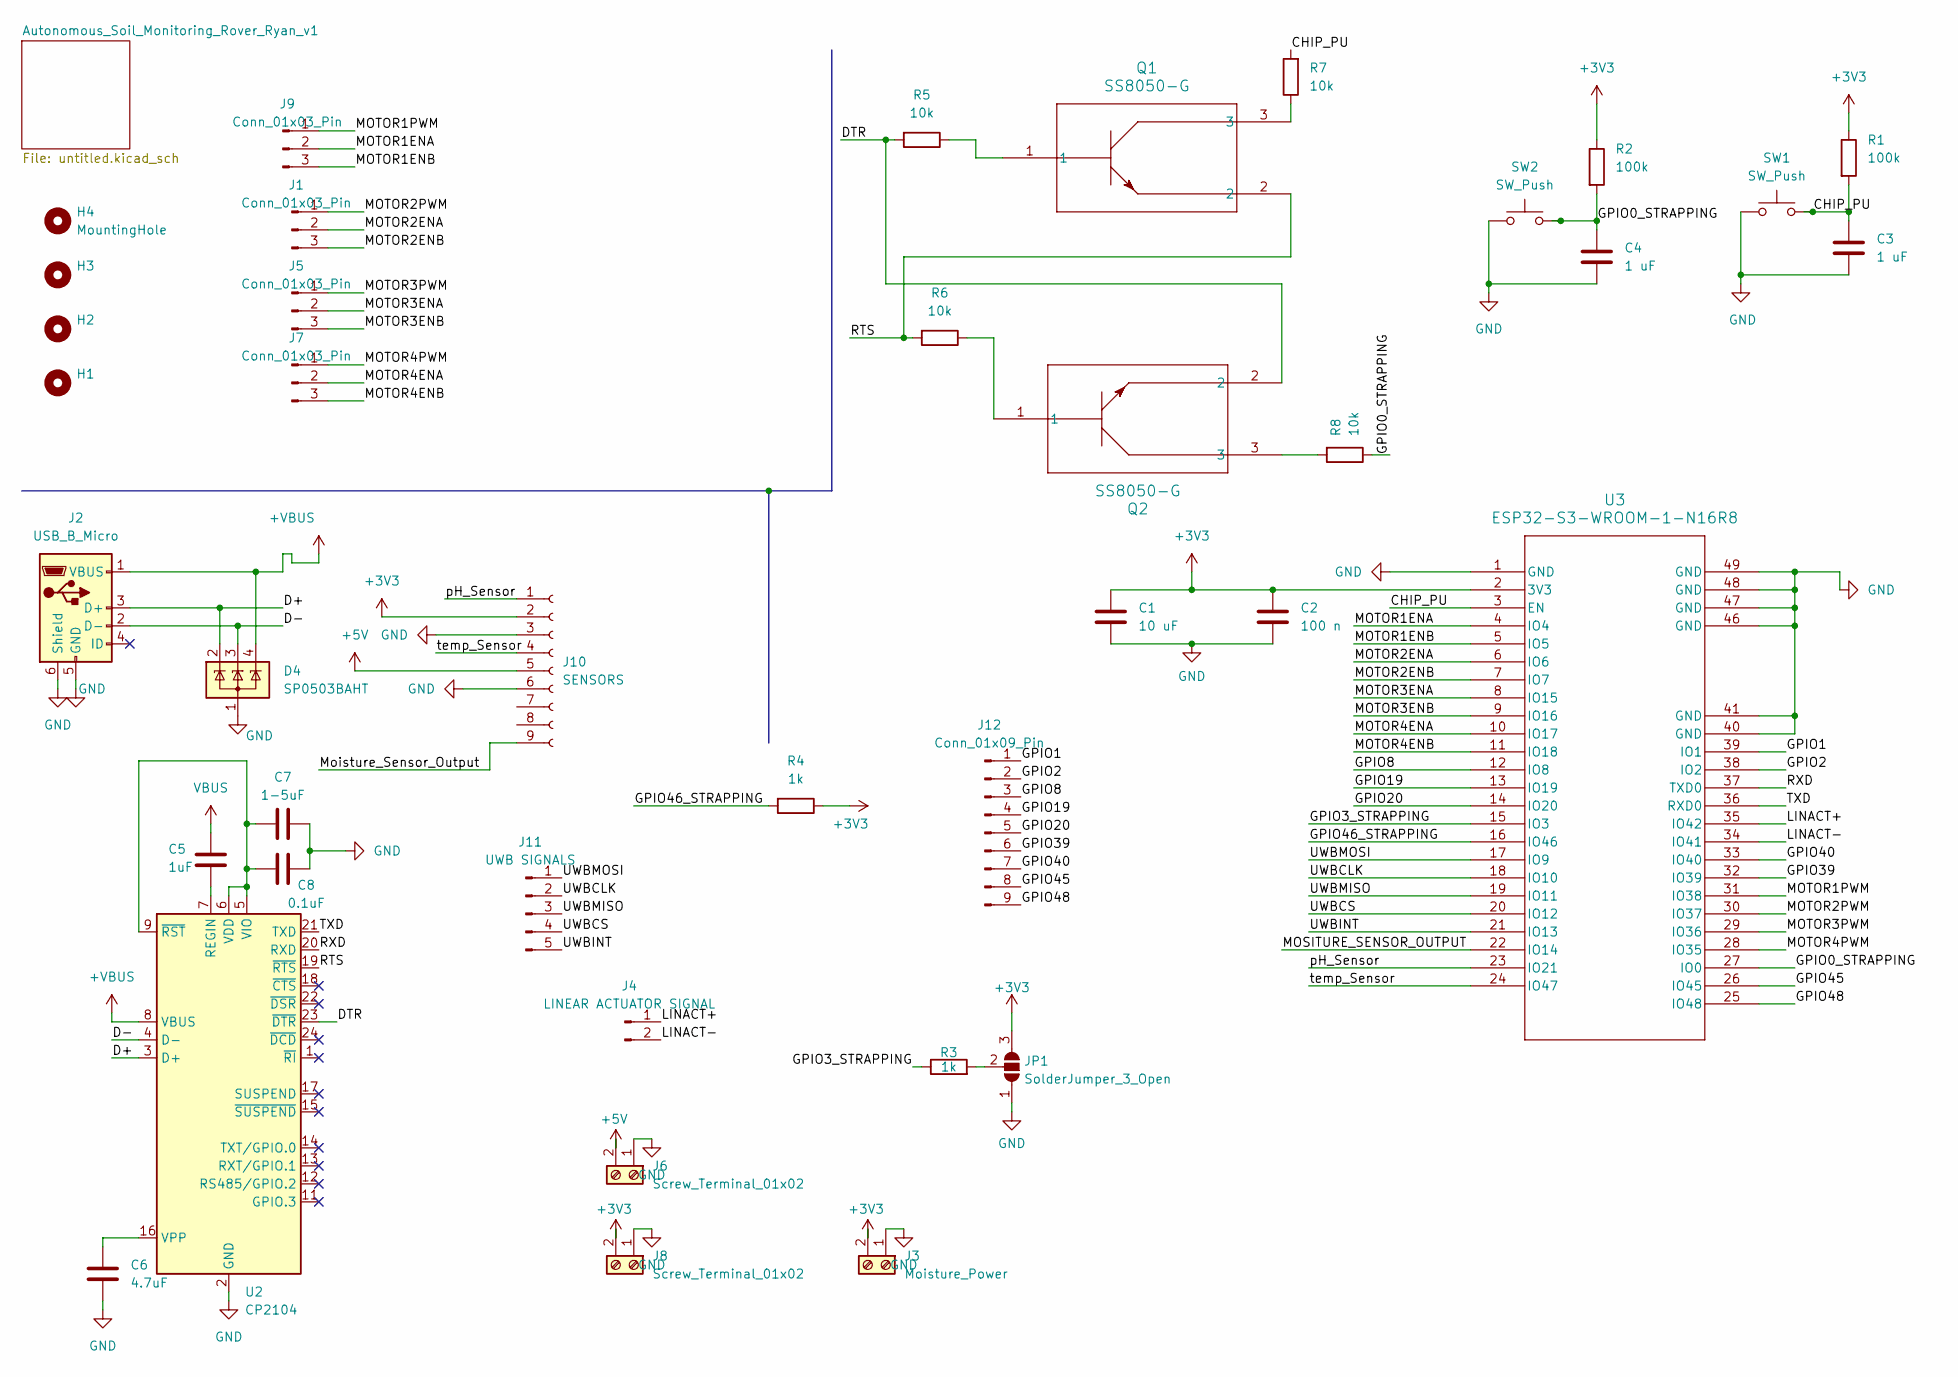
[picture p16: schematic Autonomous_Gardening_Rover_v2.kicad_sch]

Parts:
C1: 10 uF; C_0805_2012Metric_Pad1.18x1.45mm_HandSolder
C2: 100 n; C_0805_2012Metric_Pad1.18x1.45mm_HandSolder
C3, C4: 1 uF; C_0805_2012Metric_Pad1.18x1.45mm_HandSolder
C5: 1uF; C_0805_2012Metric_Pad1.18x1.45mm_HandSolder
C6: 4.7uF; C_0805_2012Metric_Pad1.18x1.45mm_HandSolder
C7: 1-5uF; C_0805_2012Metric_Pad1.18x1.45mm_HandSolder
C8: 0.1uF; C_0805_2012Metric_Pad1.18x1.45mm_HandSolder
D4: SP0503BAHT; SOT-143
H1, H2, H3, H4: MountingHole; MountingHole_3.2mm_M3
J1, J5, J7, J9: Conn_01x03_Pin; PinHeader_1x03_P2.54mm_Vertical
J2: USB_B_Micro; USB_Micro-B_Molex_47346-0001
J3: Moisture_Power; TerminalBlock_Phoenix_MKDS-1,5-2-5.08_1x02_P5.08mm_Horizont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
J4: LINEAR ACTUATOR SIGNAL; TerminalBlock_Phoenix_MKDS-1,5-2-5.08_1x02_P5.08mm_Horizont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
J6, J8: Screw_Terminal_01x02; TerminalBlock_Phoenix_MKDS-1,5-2-5.08_1x02_P5.08mm_Horizont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
J10: SENSORS; PinHeader_1x09_P2.54mm_Vertical
J11: UWB SIGNALS; PinHeader_1x05_P2.54mm_Vertical
J12: Conn_01x09_Pin; PinHeader_1x09_P2.54mm_Vertical
JP1: SolderJumper_3_Open; SolderJumper-3_P2.0mm_Open_TrianglePad1.0x1.5mm
Q1, Q2: SS8050-G; TRAN_SS8050-G_CIP
R1, R2: 100k; R_0805_2012Metric_Pad1.20x1.40mm_HandSolder
R3: 1k; R_0805_2012Metric
R4: 1k; R_0805_2012Metric_Pad1.20x1.40mm_HandSolder
R5, R6, R7, R8: 10k; R_0805_2012Metric_Pad1.20x1.40mm_HandSolder
SW1, SW2: SW_Push; SW_PUSH_6mm_H5mm
U2: CP2104; QFN-24-1EP_4x4mm_P0.5mm_EP2.6x2.6mm
U3: ESP32-S3-WROOM-1-N16R8; ESP32-S3-WROOM-1_EXP

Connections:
+3V3: C1.1, C2.1, J3.2, J8.2, J10.2, JP1.3 (B), R1.1, R2.1, R4.1, U3.2 (3V3)
+5V: J6.2, J10.5
+VBUS: D4.4 (K), J2.1 (VBUS), U2.8 (VBUS)
/CHIP_PU: C3.1, R1.2, R7.2, SW1.2, U3.3 (EN)
/D+: D4.2 (K), J2.3 (D+), U2.3 (D+)
/D-: D4.3 (K), J2.2 (D-), U2.4 (D-)
/DTR: Q2.2, R5.2, U2.23 (~DTR)
/GPIO0_STRAPPING: C4.1, R2.2, R8.1, SW2.2, U3.27 (IO0)
/GPIO1: J12.1, U3.39 (IO1)
/GPIO2: J12.2, U3.38 (IO2)
/GPIO3_STRAPPING: R3.1, U3.15 (IO3)
/GPIO8: J12.3, U3.12 (IO8)
/GPIO19: J12.4, U3.13 (IO19)
/GPIO20: J12.5, U3.14 (IO20)
/GPIO39: J12.6, U3.32 (IO39)
/GPIO40: J12.7, U3.33 (IO40)
/GPIO45: J12.8, U3.26 (IO45)
/GPIO46_STRAPPING: R4.2, U3.16 (IO46)
/GPIO48: J12.9, U3.25 (IO48)
/LINACT+: J4.1, U3.35 (IO42)
/LINACT-: J4.2, U3.34 (IO41)
/MOSITURE_SENSOR_OUTPUT: U3.22 (IO14)
/MOTOR1ENA: J9.2, U3.4 (IO4)
/MOTOR1ENB: J9.3, U3.5 (IO5)
/MOTOR1PWM: J9.1, U3.31 (IO38)
/MOTOR2ENA: J1.2, U3.6 (IO6)
/MOTOR2ENB: J1.3, U3.7 (IO7)
/MOTOR2PWM: J1.1, U3.30 (IO37)
/MOTOR3ENA: J5.2, U3.8 (IO15)
/MOTOR3ENB: J5.3, U3.9 (IO16)
/MOTOR3PWM: J5.1, U3.29 (IO36)
/MOTOR4ENA: J7.2, U3.10 (IO17)
/MOTOR4ENB: J7.3, U3.11 (IO18)
/MOTOR4PWM: J7.1, U3.28 (IO35)
/Moisture_Sensor_Output: J10.9
/RTS: Q1.2, R6.2, U2.19 (~RTS)
/RXD: U2.20 (RXD), U3.37 (TXD0)
/TXD: U2.21 (TXD), U3.36 (RXD0)
/UWBCLK: J11.2, U3.18 (IO10)
/UWBCS: J11.4, U3.20 (IO12)
/UWBINT: J11.5, U3.21 (IO13)
/UWBMISO: J11.3, U3.19 (IO11)
/UWBMOSI: J11.1, U3.17 (IO9)
/pH_Sensor: J10.1, U3.23 (IO21)
/temp_Sensor: J10.4, U3.24 (IO47)
GND: C1.2, C2.2, C3.2, C4.2, C6.2, C7.2, C8.2, D4.1 (A), J2.5 (GND), J2.6 (Shield), J3.1, J6.1, J8.1, J10.3, J10.6, JP1.1 (A), SW1.1, SW2.1, U2.2 (GND), U2.25 (GND), U3.1 (GND), U3.40 (GND), U3.41 (GND), U3.46 (GND), U3.47 (GND), U3.48 (GND), U3.49 (GND)
unnamed: JP1.2 (C), R3.2
unnamed: Q1.1, R5.1
unnamed: Q1.3, R7.1
unnamed: Q2.1, R6.1
unnamed: Q2.3, R8.2
unnamed: C5.2, U2.7 (REGIN)
unnamed: C7.1, C8.1, U2.5 (VIO), U2.6 (VDD), U2.9 (~RST)
unnamed: C6.1, U2.16 (VPP)
VBUS: C5.1

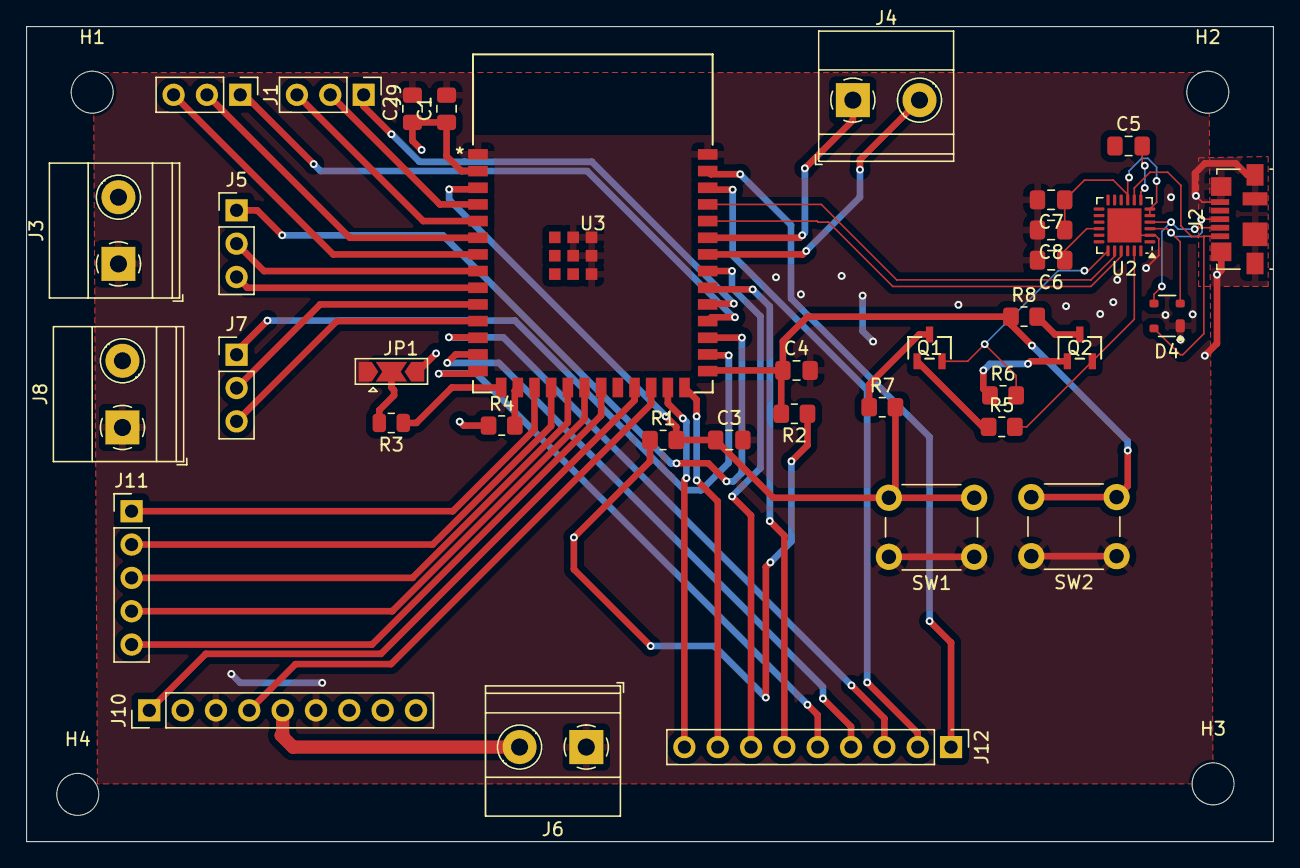
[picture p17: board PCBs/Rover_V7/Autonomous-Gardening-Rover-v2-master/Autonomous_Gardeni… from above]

Board: 2 copper layers, 95.0 x 62.1 mm, 40 parts (0 on the bottom side), 52 nets.

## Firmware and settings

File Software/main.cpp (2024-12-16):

#include <Arduino.h>
#include <BluetoothSerial.h>
#include <SPIFFS.h>

#define QUAD_ENCODER_A 27
#define QUAD_ENCODER_B 26

#define BL_QUAD_ENCODER_A 34
#define BL_QUAD_ENCODER_B 35

#define BR_MOTOR_IN1 32
#define BR_MOTOR_IN2 16

#define BL_MOTOR_IN3 17
#define BL_MOTOR_IN4 18

#define ADC_PIN 13
#define ADC_PIN2 14

#define LIN_ACTUATE 22
#define LIN_DEACTUATE 23

#define TEMP_PIN 33
#define PH_PIN 4
#define MOISTURE_PIN 25
#define ADC_RESOLUTION 4095.0
#define VOLTAGE_REF 3.3
#define ATLAS_COEFF -5.6548
#define ATLAS_CONST 15.509
#define MOISTURE_COEFF 1102033.43
#define MOISTURE_Y 1089774.62

volatile int position = 0; // Encoder position
volatile int bl_position = 0; 
volatile int direction = 0; // 1 for clockwise, -1 for counterclockwise

const int pwmChannel = 0;
const int pwmFrequency = 5000;
const int pwmResolution = 12;
const int pwmChannel_2 = 1;
int targetDistance = 1000;    // Target distance in encoder counts
// int maxSpeed = 3000;
int maxSpeed = 100;
// int accelerationStep = 100;    // Incremental speed step for acceleration and deceleration
int accelerationStep = 10;
int delayPerStep = 10;        // Delay per step during acceleration and deceleration (ms)

int stops_done = 0;

int waypoints = 4;

float alen = 0.75;

uint8_t speed;
uint8_t bl_speed;

float increment;

volatile float coord1;
volatile float coord2;

BluetoothSerial SerialBT;

void IRAM_ATTR updateEncoder() {
  int a = digitalRead(QUAD_ENCODER_A);
  int b = digitalRead(QUAD_ENCODER_B);

  int c = digitalRead(BL_QUAD_ENCODER_A);
  int d = digitalRead(BL_QUAD_ENCODER_B);

  if(a == HIGH && b == LOW){
    position += 1;
  }

  if(c == HIGH && d == LOW){
    bl_position += 1;
  }
}


void setMotor(uint8_t speed, uint8_t bl_speed, uint8_t dir){
  Serial.println(speed);
  Serial.println(bl_speed);
  if(speed == 0){
    ledcWrite(pwmChannel, 0);
    digitalWrite(BR_MOTOR_IN1, LOW);
    digitalWrite(BR_MOTOR_IN2, LOW);
  }
  else{
    ledcWrite(pwmChannel, abs(speed));
    digitalWrite(BR_MOTOR_IN2, HIGH);
    // digitalWrite(BR_MOTOR_IN2, LOW);
  }

  if(bl_speed == 0){
    ledcWrite(pwmChannel_2, 0);
    digitalWrite(BL_MOTOR_IN3, LOW);
    digitalWrite(BL_MOTOR_IN4, LOW);
  }
  else{
    ledcWrite(pwmChannel_2, abs(bl_speed));
    digitalWrite(BL_MOTOR_IN4, HIGH);
    // digitalWrite(BL_MOTOR_IN4, LOW);
  }
}


void setup() {
  Serial.begin(9600);
  SerialBT.begin("ESP32-WROOM-Receiver", true);
  SerialBT.println("Waiting for Bluetooth data...");

  // Serial.begin(9600);
  pinMode(QUAD_ENCODER_A, INPUT_PULLUP);
  pinMode(QUAD_ENCODER_B, INPUT_PULLUP);
  attachInterrupt(digitalPinToInterrupt(QUAD_ENCODER_A), updateEncoder, CHANGE);
  attachInterrupt(digitalPinToInterrupt(QUAD_ENCODER_B), updateEncoder, CHANGE);

  pinMode(BL_QUAD_ENCODER_A, INPUT_PULLUP);
  pinMode(BL_QUAD_ENCODER_B, INPUT_PULLUP);
  attachInterrupt(digitalPinToInterrupt(BL_QUAD_ENCODER_A), updateEncoder, CHANGE);
  attachInterrupt(digitalPinToInterrupt(BL_QUAD_ENCODER_B), updateEncoder, CHANGE);


  ledcSetup(pwmChannel, pwmFrequency, pwmResolution);
  ledcAttachPin(BR_MOTOR_IN1, pwmChannel);
  pinMode(BR_MOTOR_IN2, OUTPUT);

  ledcSetup(pwmChannel_2, pwmFrequency, pwmResolution);
  ledcAttachPin(BL_MOTOR_IN3, pwmChannel_2);
  pinMode(BL_MOTOR_IN4, OUTPUT);

  setMotor(0,0,0);

  int analogValue = analogRead(ADC_PIN);
  int analogValue2 = analogRead(ADC_PIN2);

  int receivedValue = map(analogValue, 0, 4095, 0, 255);
  int receivedValue2 = map(analogValue2, 0, 4095, 0, 255);

  coord1 = receivedValue/255.0 * 5.0;
  coord2 = receivedValue2/255.0 * 5.0;

  float clen = (coord1+coord2)/2;
  float blen = sqrt(clen*clen-alen*alen);
  increment = blen/waypoints;
  // Serial.println(mid_clen);

  pinMode(LIN_ACTUATE, OUTPUT);
  pinMode(LIN_DEACTUATE, OUTPUT);

  digitalWrite(LIN_ACTUATE, LOW);
  digitalWrite(LIN_DEACTUATE, LOW);

  if(!SPIFFS.begin(true)){
    Serial.println("Failed to initialize SPIFFS");
    return;
  }
  Serial.println("SPIFFS initialized successfully");

  if(SPIFFS.exists("/temperatures.txt")){
    Serial.println("File exists. Preparing data for BLE transmission:");
    File file = SPIFFS.open("/temperatures.txt", FILE_READ);

    if(file){
      SPIFFS.remove("/temperatures.txt");
      Serial.println("Previous temperatures.txt deleted");
    }
    else{
      Serial.println("Failed to open temperatures.txt for reading.");\
    }
  }

  if(SPIFFS.exists("/pH.txt")){
    Serial.println("File exists. Preparing data for BLE transmission:");
    File file = SPIFFS.open("/pH.txt", FILE_READ);

    if(file){
      SPIFFS.remove("/pH.txt");
      Serial.println("Previous pH.txt deleted");
    }
    else{
      Serial.println("Failed to open pH.txt for reading.");
    }
  }

  if(SPIFFS.exists("/moistures.txt")){
    Serial.println("File exists. Preparing data for BLE transmission:");
    File file = SPIFFS.open("/moistures.txt", FILE_READ);

    if(file){
      SPIFFS.remove("/moistures.txt");
      Serial.println("Previous moistures.txt deleted");
    }
    else{
      Serial.println("Failed to open moistures.txt for reading.");
    }
  }
}

void loop() {
  speed = 0;
  bl_speed = 0;
  speed = 0;
  bl_speed = speed;
  setMotor(speed, bl_speed, 1);
  delay(1000);
  int remaining = waypoints - stops_done;
  int height_left = increment*remaining;
  if (coord1+coord2 < 1.8) {

    Serial.println("Printing sensor file contents:");

    File tempFile = SPIFFS.open("/temperatures.txt", FILE_READ);
    if(tempFile){
      while(tempFile.available())
      {
        String tempLine = tempFile.readStringUntil('\n');
        tempLine = tempLine + "\n";
        Serial.println(tempLine);
      }
      tempFile.close();
      Serial.println("End of temperature file contents.");
    }

    File pHFile = SPIFFS.open("/pH.txt", FILE_READ);
    if(pHFile){
      while(pHFile.available())
      {
        String pHLine = pHFile.readStringUntil('\n');
        pHLine = pHLine + "\n";
        Serial.println(pHLine);
      }
      pHFile.close();
      Serial.println("End of pH file contents.");
    }

    File moisturesFile = SPIFFS.open("/moistures.txt", FILE_READ);
    if(moisturesFile){
      while(moisturesFile.available())
      {
        String moisturesLine = moisturesFile.readStringUntil('\n');
        moisturesLine = moisturesLine + "\n";
        Serial.println(moisturesLine);
      }
      moisturesFile.close();
      Serial.println("End of moisture file contents.");
    }

    delay(10000);
  }
  else if (stops_done < waypoints && (coord1+coord2)/2 < sqrt(height_left*height_left+alen*alen) + 0.2) {
    delay(1000);
    digitalWrite(LIN_ACTUATE, HIGH);
    digitalWrite(LIN_DEACTUATE, LOW);
    Serial.println("Linear Actuator Extended");

    int temperature = analogRead(TEMP_PIN);
    int pH = analogRead(PH_PIN);
    float pH_voltage = (pH / ADC_RESOLUTION) * VOLTAGE_REF;
    float pH_actual = (ATLAS_COEFF * pH_voltage) + ATLAS_CONST;
    int moisture = analogRead(MOISTURE_PIN);
    // float moisture_actual = MOISTURE_COEFF * moisture + MOISTURE_Y;

    File tempFile = SPIFFS.open("/temperatures.txt", FILE_APPEND);
    if (tempFile) {
        tempFile.println(String(temperature));
        tempFile.close();
        Serial.println("Temperature saved to SPIFFS");
    } else {
        Serial.println("Failed to open temperatures.txt for writing");
    }

    File pHFile = SPIFFS.open("/pH.txt", FILE_APPEND);
    if (pHFile) {
        pHFile.println(String(pH_actual));
        pHFile.close();
        Serial.println("PH saved to SPIFFS");
    } else {
        Serial.println("Failed to open pH.txt for writing");
    }

    //10ko 0.739
    //100 k0 0.998
    //330 k0 1.69
    //1 m0 2.55
    //2 m0 2.9
    //3 m0 2.9

    File moisturesFile = SPIFFS.open("/moistures.txt", FILE_APPEND);
    if (moisturesFile) {
        moisturesFile.println(String(moisture));
        moisturesFile.close();
        Serial.println("Moisture saved to SPIFFS");
    } else {
        Serial.println("Failed to open moistures.txt for writing");
    }
    
    delay(10000);
    digitalWrite(LIN_ACTUATE, LOW);
    digitalWrite(LIN_DEACTUATE, HIGH);
    Serial.println("Linear Actuator Retracted");
    stops_done++;
  }
  else if (coord2 > coord1 + 0.15) {
    speed = 0;
    bl_speed = 80;
    setMotor(speed, bl_speed, 1);
    Serial.println("Turning left");
    delay(200);
    speed = 80;
    bl_speed = speed;
    setMotor(speed, bl_speed, 1);
    Serial.println("Going straight");
    delay(700);
  }
  else if (coord1 > coord2 + 0.15) {
    bl_speed = 0;
    speed = 80;
    setMotor(speed, bl_speed, 1);
    Serial.println("Turning right");
    delay(200);
    speed = 80;
    bl_speed = speed;
    setMotor(speed, bl_speed, 1);
    Serial.println("Going straight");
    delay(700);
  }
  else {
    speed = 80;
    bl_speed = speed;
    setMotor(speed, bl_speed, 1);
    Serial.println("Going straight");
    delay(700);
  }

  int analogValue = analogRead(ADC_PIN);
  int analogValue2 = analogRead(ADC_PIN2);

  // Convert the analog value to match the DAC range (0-255)
  int receivedValue = map(analogValue, 0, 4095, 0, 255);
  int receivedValue2 = map(analogValue2, 0, 4095, 0, 255);

  coord1 = receivedValue/255.0 * 5.0;
  coord2 = receivedValue2/255.0 * 5.0;

  // Print the received value for debugging
  Serial.println("Received value 1: " + String(coord1));
  Serial.println("Received value 2: " + String(coord2));
}

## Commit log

2024-10-08 Add schematics
    [buck_converter.kicad_pcb, buck_converter.kicad_sch, rover.kicad_pcb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]
2024-10-08 Add PCB PDF
2024-10-08 Update PCB
    [rover.kicad_sch]
2024-10-08 Update buck converter
    [buck_converter.kicad_sch]
2024-10-11 Add linear regulator
    [linear_regulator.kicad_pcb, linear_regulator.kicad_sch]
2024-10-11 Add moisture sensor
    [ECE445_Moisture_Sensor.kicad_pcb, ECE445_Moisture_Sensor.kicad_sch]
2024-10-21 Add V2
    [Autonomous_Gardening_Rover_v2.kicad_pcb, Autonomous_Gardening_Rover_v2.kicad_sch, ECE445_Moisture_Sensor.kicad_pcb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]
2024-10-29 Update PCBS
    [Autonomous_Gardening_Rover_v2.kicad_pcb, Autonomous_Gardening_Rover_v2.kicad_sch]
2024-11-09 Update V4
    [Autonomous_Gardening_Rover_v2-12V.gbr, Autonomous_Gardening_Rover_v2-3V3.gbr, Autonomous_Gardening_Rover_v2-5V.gbr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]
2024-11-11 New version
    [Autonomous_Gardening_Rover_v2.kicad_pcb, PCB_split.kicad_pcb, power_board_fixed_regulator.kicad_pcb]
2024-11-23 Add V7
    [Autonomous_Gardening_Rover_v2-12V.gbr, Autonomous_Gardening_Rover_v2-3V3.gbr, Autonomous_Gardening_Rover_v2-5V.gbr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]
2024-11-24 Finish v7 pcb
    [Autonomous_Gardening_Rover_v2.kicad_pcb, Autonomous_Gardening_Rover_v2.kicad_sch]
2024-11-24 Final V7
    [Autonomous_Gardening_Rover_v2.kicad_pcb, Buck_V2.kicad_pcb, Buck_V2.kicad_sch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]
